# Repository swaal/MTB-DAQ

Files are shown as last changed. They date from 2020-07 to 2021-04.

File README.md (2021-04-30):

# MTB DAQ
A small and portable data acquisition system based on the PyBoard V1.1 designed to collect acceleration data while riding a mountain bike.

## About
The Mountain Bike Data Acquisition System (MTB DAQ) is a system designed to collect acceleration data while riding a mountain bike.
The system was designed as part of a Cal Poly Masters Thesis in Mechanical Engineering focused on a quantitative method for tuning mountain bike suspension. The MTB DAQ
was designed after the PyBoard V1.1 and is utilizes the same firmware. The acceleration data is stored in binary format on a Micro SD card. 

## Contents
The files included in this project provide almost everything needed to build a MTB DAQ. The folders are arranged as follows:
### BoardFiles
This folder contains all of the Autodesk Eagle schematic and board files. There are three types of boards: the Main Board, the UI Board, and the ADXL375 Board. 
The Main Board and UI Board work together to define the heart of the system, providing the computing power and user interface. The ADXL375 Board provides the necessary power filtering and connections for the ADXL375 accelerometer. The accelerometers are connected to the main board via two ethernet cables, chosen for their wide availability, low cost, and locking connection.
### MATLAB_Code
This folder contains two MATLAB files that can be used to interpret and plot the acceleration data from the binary files that are saved from the MTB DAQ.
### MicropythonCode
This folder contains the micropython files that run the MTB DAQ. Note that some of the files have been saved as *.mpy* files. This is a bytecote version of the original file. This was done in order to make the files small enough to fit in the flash memory of the microcontroller. The original files are contained within the sub folder "files_converted_to_mpy". Any modifications made to the original *.py* files can be converted into *.mpy* files using the python cross compiler *mpy-cross*. To get the system running, simply load on all the files in the MicropythonCode folder (excluding the contents in the files_converted_to_mpy subfolder) and reboot the board.
### PyBoardFirmware
A copy of the compatible PyBoard V1.1 firmware.

## Technical Specifications
- **Accelerometers:** Analog Devices ADXL375BCCZ Accelerometer
- **Number of Accelerometers Supported:** 2
- **Measurement Range:** +/- 200g
- **Output Data Rate:** 1600Hz (can be configured to go up to 3200Hz)
- **Battery Life:** > 8 hours

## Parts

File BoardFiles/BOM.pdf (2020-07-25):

ASSEMBLY | SUB ASSEMBLY | PART | DESCRIPTION | MFG. | MFG. PART NO. | SUPPLIER | SUPPLIER PART NO. | QTY/UNIT
MAIN UNIT | - | EXTRUSION | BOX ALUM NATURAL 4.72"LX3.07"W | HAMMOND MANUFACTURING | 1455J1201 | DIGIKEY | HM890-ND | 1
MAIN UNIT | - | JUMPER | JUMPER W/TEST PNT 1X2PINS 2.54MM | WÜRTH ELEKTRONIK | 60900213421 | DIGIKEY | 732-2678-ND | 1
MAIN UNIT | - | M5X0.8 35MM LONG HEX CAP
| | SCREW | SUPER-CORROSION-RESISTANT 316
| | | STAINLESS STEEL SOCKET HEAD SCREW;
| | | M5 X 0.8 MM THREAD, 35 MM LONG | | | MCMASTER | 92290A256 | 2
MAIN UNIT | - | POWER SWITCH | SWITCH ROCKER SPST 10A 125V | E-SWITCH | R6ABLKBLKFF | DIGIKEY | EG1526-ND | 1
MAIN UNIT | - | QUICK CONNECT CABLE CRIMP | CONN QC RCPT 14-18AWG 0.187 | TE CONNECTIVITY | 63316-2 | DIGIKEY | A100922CT-ND | 4
MAIN UNIT | - | RECEPTCLE SLEEVE | CONN RCPT SLEEVE 0.187 1POS CLR | TE CONNECTIVITY | 3-170823-8 | DIGIKEY | A124425-ND | 4
MAIN UNIT | - | RIBBON CABLE | CABLE ASSEM .05" 10POS F-F 2" | SAMTEC INC. | FFSD-05-D-02.00-01-N | DIGIKEY | SAM8217-ND | 1
MAIN UNIT | - | THREAD LOCKER | ADJUSTABLE THREAD LOCKER; 0.34 OZ.
| | | CAN | LOCTITE | 222 | MCMASTER | 1810A27 | 0.01
MAIN UNIT | - | SIDE PANEL 1 | | LASER CUT | | | | 1
MAIN UNIT | - | SIDE PANEL 2 | | LASER CUT | | | | 1
MAIN UNIT | MAIN BOARD | MAIN BOARD PCB | MAIN BOARD PRINTED CIRCUIT BOARD | OSHPARK | | OSHPARK | | 1
MAIN UNIT | MAIN BOARD | (-). (+) | DIGIKEY PART NO. WM6456-ND | MOLEX | 197084011 | DIGIKEY | WM6456-ND | 2
MAIN UNIT | MAIN BOARD | ADXL375_1, ADXL375_2 | DIGIKEY PART NO. RJCSE538001CT- | AMPHENOL ICC (COMMERCIAL
| | | | PRODUCTS) | RJCSE538001 | DIGIKEY | RJCSE538001CT-ND | 2
MAIN UNIT | MAIN BOARD | BAT_1, BAT_2 | PH SERIES 2 POSITION 2 MM PITCH | JST SALES AMERICA INC. | S2B-PH-SM4-TB(LF)(SN) | DIGIKEY | 455-1749-1-ND | 2
MAIN UNIT | MAIN BOARD | C1, C20, C21, C22, C23, C5 | CAP CER 0.1UF 25V X7R 0805 | KEMET | C0805C104K3RACTU | DIGIKEY | 399-1168-1-ND | 6
MAIN UNIT | MAIN BOARD | C15, C16 | CAP CER 1UF 16V X7R 0805 | KEMET | C0805C105K4RACTU | DIGIKEY | 399-1284-1-ND | 2
MAIN UNIT | MAIN BOARD | C17, C18, C19 | CAP CER 4.7UF 6.3V X5R 0805 | KEMET | C0805C475K9PACTU | DIGIKEY | 399-3134-1-ND | 3
MAIN UNIT | MAIN BOARD | C2, C8 | CAP CER 2PF 250V C0G/NP0 0805 | KEMET | CBR08C209BAGAC | DIGIKEY | 399-8701-1-ND | 2
MAIN UNIT | MAIN BOARD | C3, C4 | CAP CER 24PF 250V C0G/NP0 0805 | KEMET | CBR08C240JAGAC | DIGIKEY | 399-8758-1-ND | 2
MAIN UNIT | MAIN BOARD | C6, C7 | CAP CER 2.2UF 10V X7R 0805 | KEMET | C0805C225K8RACAUTO | DIGIKEY | 399-6951-1-ND | 2
MAIN UNIT | MAIN BOARD | C9 | CAP CER 10UF 10V X5R 0805 | KEMET | C0805C106K8PACTU | DIGIKEY | 399-4925-1-ND | 1
MAIN UNIT | MAIN BOARD | D1 | DIODE SCHOTTKY 20V 1A SOD123W | NEXPERIA USA INC. | PMEG2010ER,115 | DIGIKEY | 1727-5192-1-ND | 1
MAIN UNIT | MAIN BOARD | J1 | CONN RCPT USB2.0 MINI B SMD R/A | MOLEX | 675031020 | DIGIKEY | WM5461CT-ND | 1
MAIN UNIT | MAIN BOARD | JP1 | CONN HEADER VERT 3POS 2.54MM | WÜRTH ELEKTRONIK | 61300311121 | DIGIKEY | 732-5316-ND | 1
MAIN UNIT | MAIN BOARD | L1 | 120 OHMS @ 100MHZ 1 FERRITE BE | VISHAY DALE | ILHB0805ER121V | DIGIKEY | 541-2299-1-ND | 1
MAIN UNIT | MAIN BOARD | LED_BLU | LED BLUE CLEAR 0805 SMD | WÜRTH ELEKTRONIK | 150080BS75000 | DIGIKEY | 732-4982-1-ND | 1
MAIN UNIT | MAIN BOARD | LED_GRN | LED GREEN CLEAR 0805 SMD | WÜRTH ELEKTRONIK | 150080VS75000 | DIGIKEY | 732-4986-1-ND | 1
MAIN UNIT | MAIN BOARD | LED_RED | LED RED CLEAR 0805 SMD | WÜRTH ELEKTRONIK | 150080SS75000 | DIGIKEY | 732-4985-1-ND | 1
MAIN UNIT | MAIN BOARD | LED_YEL | LED YELLOW CLEAR 0805 SMD | WÜRTH ELEKTRONIK | 150080YS75000 | DIGIKEY | 732-4987-1-ND | 1
MAIN UNIT | MAIN BOARD | LIPO_CHG | IC CONTROLLR LI-ION 4.2V SOT23-5 | MICROCHIP TECHNOLOGY | MCP73831T-2ACI/OT | DIGIKEY | MCP73831T-
| | | | | | | 2ACI/OTCT-ND | 1
MAIN UNIT | MAIN BOARD | LITHIUM ION BATTERY | BATTERY LITHIUM 3.7V 1.2AH | ADAFRUIT INDUSTRIES LLC | 258 | DIGIKEY | 1528-1838-ND | 1
MAIN UNIT | MAIN BOARD | LITHIUM POLYMER BATTERY | BATT LITH POLY 1S1P 320MAH 3.7V | JAUCH QUARTZ | LP402535JU + PCM +
| | | | | WIRES 50MM | DIGIKEY | 1908-1354-ND | 4
MAIN UNIT | MAIN BOARD | R1, R13, R5, R6, R8 | RES SMD 100K OHM 1% 1/3W 0805 | TE CONNECTIVITY | CRGH0805F100K | DIGIKEY | A126415CT-ND | 5
MAIN UNIT | MAIN BOARD | R11 | RES SMD 2K OHM 0.1% 1/4W 0805 | TE CONNECTIVITY | RP73PF2A2K0BTDF | DIGIKEY | A110572CT-ND | 1
MAIN UNIT | MAIN BOARD | R19, R20, R21, R22, R3 | CRGCQ 0805 4K7 1% | TE CONNECTIVITY | CRGCQ0805F4K7 | DIGIKEY | A129757CT-ND | 5
MAIN UNIT | MAIN BOARD | R2, R10, R15, R16, R17, R18 | RES SMD 560 OHM 1% 1/8W 0805 | TE CONNECTIVITY | CRG0805F560R | DIGIKEY | A126376CT-ND | 6
MAIN UNIT | MAIN BOARD | R7, R9 | RES SMD 22 OHM 1% 1/8W 0805 | TE CONNECTIVITY | CRG0805F22R | DIGIKEY | A126352CT-ND | 2
MAIN UNIT | MAIN BOARD | RESET | SWITCH TACTILE SPST-NO 0.05A 12V | E-SWITCH | TL3301FF160QG | DIGIKEY | EG4375CT-ND | 1
MAIN UNIT | MAIN BOARD | SD_SLOT | CONN MICRO SD CARD PUSH-PUSH R/A | MOLEX | 5027740891 | DIGIKEY | WM24066CT-ND | 1
MAIN UNIT | MAIN BOARD | STM32F405RGT6 | IC MCU 32BIT 1MB FLASH 64LQFP | STMICROELECTRONICS | STM32F405RGT6 | DIGIKEY | 497-11767-ND | 1
MAIN UNIT | MAIN BOARD | U1 | IC REG LINEAR 3.3V 1A SOT223 | DIODES INCORPORATED | AZ1117EH-3.3TRG1 | DIGIKEY | AZ1117EH-
| | | | | | | 3.3TRG1DICT-ND | 1
MAIN UNIT | MAIN BOARD | X1 | CONN HEADER SMD 10POS 1.27MM | SAMTEC INC. | SHF-105-01-L-D-SM | DIGIKEY | SAM10710-ND | 1
MAIN UNIT | MAIN BOARD | XTAL | CRYSTAL 12.0000MHZ 18PF SMD | ECS INC. | ECS-120-18-5PX-TR | DIGIKEY | XC1289CT-ND | 1
MAIN UNIT | MAIN BOARD | Y1 | CRYSTAL 32.7680KHZ 6PF SMD | ABRACON LLC | ABS25-32.768KHZ-6-1-T | DIGIKEY | 535-10241-1-ND | 1
MAIN UNIT | UI BOARD | UI BOARD PCB | UI BOARD PRINTED CIRCUIT BOARD | OSHPARK | | OSHPARK | | 1
MAIN UNIT | UI BOARD | LED HOLDER | LED HOLDER | 3D PRINTED | | | | 1
MAIN UNIT | UI BOARD | 7 SEGMENT DISPLAY | QUAD ALPHANUMERIC DISPLAY - RED 0.54"
| | | DIGITS W/ I2C BACKPACK | ADAFRUIT INDUSTRIES LLC | 1911 | ADAFRUIT | 1911 | 1
MAIN UNIT | UI BOARD | CHG | PNL MNT W/ WIRE 590NM 25MCD YLW | BIVAR INC. | MPR5YD | DIGIKEY | 492-1576-ND | 1
MAIN UNIT | UI BOARD | PWR | PNL MNT W/ WIRE 568NM 25MCD GRN | BIVAR INC. | MPR5GD | DIGIKEY | 492-1571-ND | 1
MAIN UNIT | UI BOARD | R1, R3 | RES SMD 44.2 OHM 0.1% 1/4W 0805 | TE CONNECTIVITY | 8-1625868-9 | DIGIKEY | A110413CT-ND | 2
MAIN UNIT | UI BOARD | R2 | RES SMD 80.6 OHM 0.1% 1/4W 0805 | TE CONNECTIVITY | 1-2176091-5 | DIGIKEY | A110438CT-ND | 1
MAIN UNIT | UI BOARD | R4 | CRGCQ 0805 4K7 1% | TE CONNECTIVITY | CRGCQ0805F4K7 | DIGIKEY | A129757CT-ND | 1
MAIN UNIT | UI BOARD | REC | PNL MNT W/ WIRE 625NM 25MCD RED | BIVAR INC. | MPR5HD | DIGIKEY | 492-1573-ND | 1
| | | SPLINED PRESS-FIT THREADED STANDOFFS WITH OPEN END; MINIATURE, 2.4MM OD, 2MM LONG
MAIN UNIT | UI BOARD | U$4 | SWITCH PUSHBUTTON SPST-NO 2A 48V | E-SWITCH | PV0H240SS | DIGIKEY | EG5385-ND | 1
MAIN UNIT | UI BOARD | STANDOFFS | | | | MCMASTER | 92985A815 | 4
MAIN UNIT | UI BOARD | X1 | CONN HEADER SMD 10POS 1.27MM | SAMTEC INC. | SHF-105-01-L-D-SM | DIGIKEY | SAM10710-ND | 1

ASSEMBLY | SUB ASSEMBLY | PART | DESCRIPTION | MFG. | MFG. PART NO. | SUPPLIER | SUPPLIER PART NO. | QTY/UNIT
MAIN UNIT | UI BOARD | | 316 STAINLESS STEEL WASHER; FOR
| | | NUMBER 3 SCREW SIZE, 0.109" ID, 0.25" OD | | | MCMASTER | 90107A004 | 4
MAIN UNIT | UI BOARD | | ALUMINUM UNTHREADED SPACER; 1/4" OD,
| | | 3/16" LONG, FOR NUMBER 2 SCREW SIZE | | | MCMASTER | 92510A401 | 4
MAIN UNIT | UI BOARD | | 18-8 STAINLESS STEEL WASHER FOR M1 SCREW SIZE, 1.1 MM ID, 3.2 MM OD | | MCMASTER | 93475A154 | 8
| | | 18-8 STAINLESS STEEL NARROW CHEESE HEAD SLOTTED SCREWS; M1 X 0.25MM THREAD, 10MM LONG
FRONT ACCELEROMETER UNIT | ADXL375 BOARD | ADXL375 BOARD PCB | ADXL375 BOARD PRINTED CIRCUIT BOARD | OSHPARK | OSHPARK | | 1
MAIN UNIT | UI BOARD
MCMASTER | 91800A062 | 4
FRONT ACCELEROMETER UNIT | ADXL375 BOARD | U1 | IC GATE OR 1CH 2-INP SC70-5 | TEXAS INSTRUMENTS | SN74LVC1G32DCKR | DIGIKEY | 296-9848-1-ND | 1
FRONT ACCELEROMETER UNIT | ADXL375 BOARD | RJ45 | DIGIKEY PART NO. RJCSE538001CT- | AMPHENOL ICC (COMMERCIAL
| | | | PRODUCTS) | RJCSE538001 | DIGIKEY | RJCSE538001CT-ND | 1
FRONT ACCELEROMETER UNIT | ADXL375 BOARD | L1 | FERRITE BEAD 30 OHM 0805 1LN | BOURNS INC. | MH2029-300Y | DIGIKEY | MH2029-300YCT-ND | 1
FRONT ACCELEROMETER UNIT | ADXL375 BOARD | C3, C1 | CAP CER 0.1UF 25V X7R 0805 | KEMET | C0805C104K3RACTU | DIGIKEY | 399-1168-1-ND | 2
FRONT ACCELEROMETER UNIT | ADXL375 BOARD | C2 | CAP CER 10UF 10V X5R 0805 | KEMET | C0805C106K8PACTU | DIGIKEY | 399-4925-1-ND | 1
FRONT ACCELEROMETER UNIT | ADXL375 BOARD | ADXL375 | ACCELEROMETER 200G I2C/SPI 14LGA | ANALOG DEVICES INC. | ADXL375BCCZ | DIGIKEY | ADXL375BCCZ-ND | 1
FRONT ACCELEROMETER UNIT | - | FRONT MOUNT BLOCK | FRONT MOUNT BLOCK | 3D PRINTED | | | | 1
FRONT ACCELEROMETER UNIT | - | FRONT COVER | FRONT COVER RUBBER-CUSHIONED U-BOLT; 304 | 3D PRINTED | | | 1
| | | STAINLESS STEEL, 3/8"-16 THREAD SIZE, 1-7/8" ID
FRONT ACCELEROMETER UNIT | - | M3X0.5 BRASS INSERTS | BRASS HEAT-SET INSERTS FOR PLASTIC; M3 X 0.50 MM THREAD SIZE, 5.700 MM INSTALLED LENGTH | | MCMASTER | 94459A140 | 4
| | | STAINLESS STEEL PAN HEAD SCREWS; WITH EXTERNAL-TOOTH WASHER, M3 X 0.5 MM THREAD, 6 MM LONG
FRONT ACCELEROMETER UNIT | - | 1/4" WASHER | 316 STAINLESS STEEL WASHER; FOR 1/4" SCREW SIZE, 0.281" ID, 0.625" OD | | MCMASTER | 90107A029 | 4
FRONT ACCELEROMETER UNIT | - | LARGE U-BOLT
MCMASTER | 30555T43 | 2
FRONT ACCELEROMETER UNIT | - | SCREW; PHILLIPS; M3X0.5X6
MCMASTER | 90317A523 | 4
REAR ACCELEROMETER UNIT | ADXL375 BOARD | ADXL375 BOARD PCB | ADXL375 BOARD PRINTED CIRCUIT BOARD | OSHPARK | | OSHPARK | | 1
REAR ACCELEROMETER UNIT | ADXL375 BOARD | U1 | IC GATE OR 1CH 2-INP SC70-5 | TEXAS INSTRUMENTS | SN74LVC1G32DCKR | DIGIKEY | 296-9848-1-ND | 1
REAR ACCELEROMETER UNIT | ADXL375 BOARD | RJ45 | DIGIKEY PART NO. RJCSE538001CT- | AMPHENOL ICC (COMMERCIAL
| | | | PRODUCTS) | RJCSE538001 | DIGIKEY | RJCSE538001CT-ND | 1
REAR ACCELEROMETER UNIT | ADXL375 BOARD | L1 | FERRITE BEAD 30 OHM 0805 1LN | BOURNS INC. | MH2029-300Y | DIGIKEY | MH2029-300YCT-ND | 1
REAR ACCELEROMETER UNIT | ADXL375 BOARD | C3, C1 | CAP CER 0.1UF 25V X7R 0805 | KEMET | C0805C104K3RACTU | DIGIKEY | 399-1168-1-ND | 2
REAR ACCELEROMETER UNIT | ADXL375 BOARD | C2 | CAP CER 10UF 10V X5R 0805 | KEMET | C0805C106K8PACTU | DIGIKEY | 399-4925-1-ND | 1
REAR ACCELEROMETER UNIT | ADXL375 BOARD | ADXL375 | ACCELEROMETER 200G I2C/SPI 14LGA | ANALOG DEVICES INC. | ADXL375BCCZ | DIGIKEY | ADXL375BCCZ-ND | 1
REAR ACCELEROMETER UNIT | - | REAR MOUNT BLOCK | REAR MOUNT BLOCK | 3D PRINTED | | | | 1
REAR ACCELEROMETER UNIT | - | REAR COVER | REAR COVER | 3D PRINTED | | | | 1
REAR ACCELEROMETER UNIT | - | REAR TRIANGLE ADAPTER | REAR TRIANGLE ADAPTER RUBBER-CUSHIONED U-BOLT; 304 | 3D PRINTED | | | 1
| | | STAINLESS STEEL, 1/4"-20 THREAD SIZE, 1-1/4" ID
REAR ACCELEROMETER UNIT | - | M3X0.5 BRASS INSERTS | BRASS HEAT-SET INSERTS FOR PLASTIC; M3 X 0.50 MM THREAD SIZE, 5.700 MM INSTALLED LENGTH | | MCMASTER | 94459A140 | 4
| | | STAINLESS STEEL PAN HEAD SCREWS; WITH EXTERNAL-TOOTH WASHER, M3 X 0.5 MM THREAD, 6 MM LONG
REAR ACCELEROMETER UNIT | - | 1/4" WASHER | 316 STAINLESS STEEL WASHER; FOR 1/4" SCREW SIZE, 0.281" ID, 0.625" OD | | MCMASTER | 90107A029 | 4
REAR ACCELEROMETER UNIT | - | SMALL U-BOLT
MCMASTER | 30555T42 | 2
REAR ACCELEROMETER UNIT | - | SCREW; PHILLIPS; M3X0.5X6
MCMASTER | 90317A523 | 4

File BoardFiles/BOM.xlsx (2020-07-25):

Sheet: MASTER
 | UNIT TOTAL | 265.8501333 |  | ORDER TOTAL | 0
ASSEMBLY | SUB ASSEMBLY | PART | VALUE | DEVICE | PACKAGE | DESCRIPTION | MFG. | MFG. PART NO. | SUPPLIER | SUPPLIER PART NO. | LINK | QTY/UNIT | PRICE | EA -> EA | QTY. | TOTAL | EXTRA TO ORDER | TOTAL ORDERED | ORDER PRICE
MAIN UNIT | - | EXTRUSION | - |  |  | BOX ALUM NATURAL 4.72"LX3.07"W | Hammond Manufacturing | 1455J1201 | DIGIKEY | HM890-ND | https://www.digikey.com/product-detail/en/hammond-manufacturing/1455J1201/HM890-ND/1090702 | 1 | 18.21 | 1 | 1 | 18.21
MAIN UNIT | - | JUMPER | - |  |  | JUMPER W/TEST PNT 1X2PINS 2.54MM | Würth Elektronik | 60900213421 | DIGIKEY | 732-2678-ND | https://www.digikey.com/product-detail/en/würth-elektronik/60900213421/732-2678-ND/2508447 | 1 | 0.3 | 1 | 1 | 0.3
MAIN UNIT | - | M5X0.8 35MM LONG HEX CAP SCREW |  |  |  | Super-Corrosion-Resistant 316 Stainless Steel Socket Head Screw; M5 x 0.8 mm Thread, 35 mm Long |  |  | MCMASTER | 92290A256 | https://www.mcmaster.com/92290a256 | 2 | 6.55 | 10 | 1 | 6.55
MAIN UNIT | - | POWER SWITCH | - |  |  | SWITCH ROCKER SPST 10A 125V | E-Switch | R6ABLKBLKFF | DIGIKEY | EG1526-ND | https://www.digikey.com/product-detail/en/e-switch/R6ABLKBLKFF/EG1526-ND/301973 | 1 | 1.61 | 1 | 1 | 1.61
MAIN UNIT | - | QUICK CONNECT CABLE CRIMP | - |  |  | CONN QC RCPT 14-18AWG 0.187 | TE Connectivity AMP Connectors | 63316-2 | DIGIKEY | A100922CT-ND | https://www.digikey.com/product-detail/en/te-connectivity-amp-connectors/63316-2/A100922CT-ND/2259591 | 4 | 0.22 | 1 | 4 | 0.88
MAIN UNIT | - | RECEPTCLE SLEEVE | - |  |  | CONN RCPT SLEEVE 0.187 1POS CLR | TE Connectivity AMP Connectors | 3-170823-8 | DIGIKEY | A124425-ND | https://www.digikey.com/product-detail/en/te-connectivity-amp-connectors/3-170823-8/A124425-ND/2284645 | 4 | 0.18 | 1 | 4 | 0.72
MAIN UNIT | - | RIBBON CABLE | - |  |  | CABLE ASSEM .05" 10POS F-F 2" | Samtec Inc. | FFSD-05-D-02.00-01-N | DIGIKEY | SAM8217-ND | https://www.digikey.com/product-detail/en/samtec-inc/FFSD-05-D-02-00-01-N/SAM8217-ND/1106576 | 1 | 11.18 | 1 | 1 | 11.18
MAIN UNIT | - | THREAD LOCKER |  |  |  | ADJUSTABLE THREAD LOCKER; 0.34 OZ. CAN | LOCTITE | 222 | MCMASTER | 1810A27 | https://www.mcmaster.com/1810a27 | 0.01 | 15.35 | 1 | 1 | 15.35
MAIN UNIT | - | SIDE PANEL 1 |  |  |  |  | LASER CUT
MAIN UNIT | - | SIDE PANEL 2 |  |  |  |  | LASER CUT
MAIN UNIT | MAIN BOARD | MAIN BOARD PCB |  |  |  | MAIN BOARD PRINTED CIRCUIT BOARD | OSHPARK |  | OSHPARK |  |  | 1 | 70.9 | 3 | 1 | 23.63333333
MAIN UNIT | MAIN BOARD | (-). (+) | QUICK_CONNECT_0.187" | QUICK_CONNECT_0.187" | QUICK_CONNECT_0.187" | DIGIKEY PART NO. WM6456-ND | MOLEX | 197084011 | DIGIKEY | WM6456-ND | https://www.digikey.com/product-detail/en/molex/0197084011/WM6456-ND/459342 | 2 | 0.22 | 1 | 0.44 | 0.0968
MAIN UNIT | MAIN BOARD | ADXL375_1, ADXL375_2 | RJ45_SURFACE_MOUNT | RJ45_SURFACE_MOUNT | RJ45_SURFACE_MOUNT | Digikey Part No. RJCSE538001CT- | Amphenol ICC (Commercial Products) | RJCSE538001 | DIGIKEY | RJCSE538001CT-ND | https://www.digikey.com/products/en?keywords=RJCSE538001CT | 2 | 1.6 | 1 | 2 | 3.2
MAIN UNIT | MAIN BOARD | BAT_1, BAT_2 | S2B-PH-SM4-TB(LF)(SN) | S2B-PH-SM4-TB(LF)(SN) | JST_S2B-PH-SM4-TB(LF)(SN) | PH Series 2 Position 2 mm Pitch | JST Sales America Inc. | S2B-PH-SM4-TB(LF)(SN) | DIGIKEY | 455-1749-1-ND | https://www.digikey.com/product-detail/en/jst-sales-america-inc/S2B-PH-SM4-TB(LF)(SN)/455-1749-1-ND/926846 | 2 | 0.58 | 1 | 2 | 1.16
MAIN UNIT | MAIN BOARD | C1, C20, C21, C22, C23, C5 | 0.1uF | C-USC0805 | C0805 | CAP CER 0.1UF 25V X7R 0805 | KEMET | C0805C104K3RACTU | DIGIKEY | 399-1168-1-ND | https://www.digikey.com/product-detail/en/kemet/C0805C104K3RACTU/399-1168-1-ND/411443 | 6 | 0.15 | 1 | 6 | 0.9
MAIN UNIT | MAIN BOARD | C15, C16 | 1uF | C-USC0805 | C0805 | CAP CER 1UF 16V X7R 0805 | KEMET | C0805C105K4RACTU | DIGIKEY | 399-1284-1-ND | https://www.digikey.com/product-detail/en/kemet/C0805C105K4RACTU/399-1284-1-ND/416060 | 2 | 0.15 |  | 2 | 0.3
MAIN UNIT | MAIN BOARD | C17, C18, C19 | 4.7uF | C-USC0805 | C0805 | CAP CER 4.7UF 6.3V X5R 0805 | KEMET | C0805C475K9PACTU | DIGIKEY | 399-3134-1-ND | https://www.digikey.com/product-detail/en/kemet/C0805C475K9PACTU/399-3134-1-ND/551639 | 3 | 0.21 |  | 3 | 0.63
MAIN UNIT | MAIN BOARD | C2, C8 | 2pF | C-USC0805 | C0805 | CAP CER 2PF 250V C0G/NP0 0805 | KEMET | CBR08C209BAGAC | DIGIKEY | 399-8701-1-ND | https://www.digikey.com/product-detail/en/kemet/CBR08C209BAGAC/399-8701-1-ND/3480301 | 2 | 1.49 |  | 2 | 2.98
MAIN UNIT | MAIN BOARD | C3, C4 | 24pF | C-USC0805 | C0805 | CAP CER 24PF 250V C0G/NP0 0805 | KEMET | CBR08C240JAGAC | DIGIKEY | 399-8758-1-ND | https://www.digikey.com/product-detail/en/kemet/CBR08C240JAGAC/399-8758-1-ND/3481277 | 2 | 1.72 |  | 2 | 3.44
MAIN UNIT | MAIN BOARD | C6, C7 | 2.2uF | C-USC0805 | C0805 | CAP CER 2.2UF 10V X7R 0805 | KEMET | C0805C225K8RACAUTO | DIGIKEY | 399-6951-1-ND | https://www.digikey.com/product-detail/en/kemet/C0805C225K8RACAUTO/399-6951-1-ND/3314459 | 2 | 0.25 |  | 2 | 0.5
MAIN UNIT | MAIN BOARD | C9 | 10uF | C-USC0805 | C0805 | CAP CER 10UF 10V X5R 0805 | KEMET | C0805C106K8PACTU | DIGIKEY | 399-4925-1-ND | https://www.digikey.com/product-detail/en/kemet/C0805C106K8PACTU/399-4925-1-ND/1090920 | 1 | 0.16 |  | 1 | 0.16
MAIN UNIT | MAIN BOARD | D1 | DIODE_SCHOTTKY | DIODE_SCHOTTKY | DIODE_SOD123W_1P9X2P8 | DIODE SCHOTTKY 20V 1A SOD123W | Nexperia USA Inc. | PMEG2010ER,115 | DIGIKEY | 1727-5192-1-ND | https://www.digikey.com/product-detail/en/nexperia-usa-inc/PMEG2010ER-115/1727-5192-1-ND/2531791 | 1 | 0.35 | 1 | 1 | 0.35
MAIN UNIT | MAIN BOARD | J1 | USB_MINI-B_SMT | USB_MINI-B_SMT | USB-MINIB | CONN RCPT USB2.0 MINI B SMD R/A | Molex | 675031020 | DIGIKEY | WM5461CT-ND | https://www.digikey.com/product-detail/en/molex/0675031020/WM5461CT-ND/1624427 | 1 | 1.08 |  | 1 | 1.08
MAIN UNIT | MAIN BOARD | JP1 |  | PINHD-1X3 | 1X03 | CONN HEADER VERT 3POS 2.54MM | Würth Elektronik | 61300311121 | DIGIKEY | 732-5316-ND | https://www.digikey.com/product-detail/en/würth-elektronik/61300311121/732-5316-ND/4846825 | 1 | 0.13 |  | 1 | 0.13
MAIN UNIT | MAIN BOARD | L1 | 1K | BEAD_120OHMS_100MHZ | IND_VISHAY_ILHB0805 | 120 Ohms @ 100MHz 1 Ferrite Be | Vishay Dale | ILHB0805ER121V | DIGIKEY | 541-2299-1-ND | https://www.digikey.com/product-detail/en/vishay-dale/ILHB0805ER121V/541-2299-1-ND/5168396 | 1 | 0.12 | 1 | 1 | 0.12
MAIN UNIT | MAIN BOARD | LED_BLU | LED_0805LED_0805 | LED_0805LED_0805 | 805 | LED BLUE CLEAR 0805 SMD | Würth Elektronik | 150080BS75000 | DIGIKEY | 732-4982-1-ND | https://www.digikey.com/product-detail/en/würth-elektronik/150080BS75000/732-4982-1-ND/4489910 | 1 | 0.18 |  | 1 | 0.18
MAIN UNIT | MAIN BOARD | LED_GRN | LED_0805LED_0805 | LED_0805LED_0805 | 805 | LED GREEN CLEAR 0805 SMD | Würth Elektronik | 150080VS75000 | DIGIKEY | 732-4986-1-ND | https://www.digikey.com/product-detail/en/würth-elektronik/150080VS75000/732-4986-1-ND/4489922 | 1 | 0.18 |  | 1 | 0.18
MAIN UNIT | MAIN BOARD | LED_RED | LED_0805LED_0805 | LED_0805LED_0805 | 805 | LED RED CLEAR 0805 SMD | Würth Elektronik | 150080SS75000 | DIGIKEY | 732-4985-1-ND | https://www.digikey.com/product-detail/en/würth-elektronik/150080SS75000/732-4985-1-ND/4489919 | 1 | 0.18 |  | 1 | 0.18
MAIN UNIT | MAIN BOARD | LED_YEL | LED_0805LED_0805 | LED_0805LED_0805 | 805 | LED YELLOW CLEAR 0805 SMD | Würth Elektronik | 150080YS75000 | DIGIKEY | 732-4987-1-ND | https://www.digikey.com/product-detail/en/würth-elektronik/150080YS75000/732-4987-1-ND/4489925 | 1 | 0.18 |  | 1 | 0.18
MAIN UNIT | MAIN BOARD | LIPO_CHG | LIPO_CHARGER_MCP73831/2 | LIPO_CHARGER_MCP73831/2 | SOT23-5 | IC CONTROLLR LI-ION 4.2V SOT23-5 | Microchip Technology | MCP73831T-2ACI/OT | DIGIKEY | MCP73831T-2ACI/OTCT-ND | https://www.digikey.com/product-detail/en/microchip-technology/MCP73831T-2ACI-OT/MCP73831T-2ACI-OTCT-ND/1979802 | 1 | 0.56 | 1 | 1 | 0.56
MAIN UNIT | MAIN BOARD | LITHIUM ION BATTERY |  |  |  | BATTERY LITHIUM 3.7V 1.2AH | Adafruit Industries LLC | 258 | DIGIKEY | 1528-1838-ND | https://www.digikey.com/product-detail/en/adafruit-industries-llc/258/1528-1838-ND/5054544 | 1 | 9.95 | 1 | 1 | 9.95
MAIN UNIT | MAIN BOARD | LITHIUM POLYMER BATTERY |  |  |  | BATT LITH POLY 1S1P 320MAH 3.7V | Jauch Quartz | LP402535JU + PCM + WIRES 50MM | DIGIKEY | 1908-1354-ND | https://www.digikey.com/product-detail/en/jauch-quartz/LP402535JU---PCM---WIRES-50MM/1908-1354-ND/9560977 | 4 | 9.54 | 1 | 4 | 38.16
MAIN UNIT | MAIN BOARD | R1, R13, R5, R6, R8 | 100K | R-US_R0805 | R0805 | RES SMD 100K OHM 1% 1/3W 0805 | TE Connectivity Passive Product | CRGH0805F100K | DIGIKEY | A126415CT-ND | https://www.digikey.com/product-detail/en/te-connectivity-passive-product/CRGH0805F100K/A126415CT-ND/7603470 | 5 | 0.1 | 1 | 5 | 0.5
MAIN UNIT | MAIN BOARD | R11 | 10K | R-US_R0805 | R0805 | RES SMD 10K OHM 0.1% 1/4W 0805 | TE Connectivity Passive Product | 2176093-5 | DIGIKEY | A110639CT-ND | https://www.digikey.com/products/en/resistors/chip-resistor-surface-mount/52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 | 1 | 0.5 |  | 1 | 0.5
MAIN UNIT | MAIN BOARD | R19, R20, R21, R22, R3 | 4.7K | R-US_R0805 | R0805 | CRGCQ 0805 4K7 1% | TE Connectivity Passive Product | CRGCQ0805F4K7 | DIGIKEY | A129757CT-ND | https://www.digikey.com/product-detail/en/te-connectivity-passive-product/CRGCQ0805F4K7/A129757CT-ND/8577589 | 5 | 0.1 |  | 5 | 0.5
MAIN UNIT | MAIN BOARD | R2, R10, R15, R16, R17, R18 | 560 | R-US_R0805 | R0805 | RES SMD 560 OHM 1% 1/8W 0805 | TE Connectivity Passive Product | CRG0805F560R | DIGIKEY | A126376CT-ND | https://www.digikey.com/product-detail/en/te-connectivity-passive-product/CRG0805F560R/A126376CT-ND/7603431 | 6 | 0.1 | 1 | 6 | 0.6
MAIN UNIT | MAIN BOARD | R7, R9 | 22 | R-US_R0805 | R0805 | RES SMD 22 OHM 1% 1/8W 0805 | TE Connectivity Passive Product | CRG0805F22R | DIGIKEY | A126352CT-ND | https://www.digikey.com/product-detail/en/te-connectivity-passive-product/CRG0805F22R/A126352CT-ND/7603407 | 2 | 0.1 | 1 | 2 | 0.2
MAIN UNIT | MAIN BOARD | RESET | SWITCH | SWITCH | SWITCH_FSM6JSMATR | SWITCH TACTILE SPST-NO 0.05A 12V | E-Switch | TL3301FF160QG | DIGIKEY | EG4375CT-ND | https://www.digikey.com/product-detail/en/e-switch/TL3301FF160QG/EG4375CT-ND/1144805 | 1 | 0.41 | 1 | 1 | 0.41
MAIN UNIT | MAIN BOARD | SD_SLOT | MICRO_SD_SLOT | MICRO_SD_SLOT |  | CONN MICRO SD CARD PUSH-PUSH R/A | Molex | 5027740891 | DIGIKEY | WM24066CT-ND | https://www.digikey.com/product-detail/en/molex/5027740891/WM24066CT-ND/1952536 | 1 | 2.45 | 1 | 1 | 2.45
MAIN UNIT | MAIN BOARD | STM32F405RGT6 | STM32F405RGT6 | STM32F405RG | TQFP64 | IC MCU 32BIT 1MB FLASH 64LQFP | STMicroelectronics | STM32F405RGT6 | DIGIKEY | 497-11767-ND | https://www.digikey.com/product-detail/en/stmicroelectronics/STM32F405RGT6/497-11767-ND/2754208 | 1 | 11.61 | 1 | 1 | 11.61
MAIN UNIT | MAIN BOARD | U1 | AZ1117EH-3.3TRG1 | AZ1117EH-3.3TRG1 | SOT230P700X180-4N | IC REG LINEAR 3.3V 1A SOT223 | Diodes Incorporated | AZ1117EH-3.3TRG1 | DIGIKEY | AZ1117EH-3.3TRG1DICT-ND | https://www.digikey.com/product-detail/en/diodes-incorporated/AZ1117EH-3.3TRG1/AZ1117EH-3.3TRG1DICT-ND/5001336! | 1 | 0.42 | 1 | 1 | 0.42
MAIN UNIT | MAIN BOARD | X1 |  |  |  | CONN HEADER SMD 10POS 1.27MM | Samtec Inc. | SHF-105-01-L-D-SM | DIGIKEY | SAM10710-ND | https://www.digikey.com/product-detail/en/samtec-inc/SHF-105-01-L-D-SM/SAM10710-ND/6561669 | 1 | 2.78 | 1 | 1 | 2.78
MAIN UNIT | MAIN BOARD | XTAL | 12MHZ | XTAL_SFM | HC-49/US | CRYSTAL 12.0000MHZ 18PF SMD | ECS Inc. | ECS-120-18-5PX-TR | DIGIKEY | XC1289CT-ND | https://www.digikey.com/product-detail/en/ecs-inc/ECS-120-18-5PX-TR/XC1289CT-ND/827753 | 1 | 0.5 | 1 | 1 | 0.5
MAIN UNIT | MAIN BOARD | Y1 | 32.768KHZ |  | 4-SOJ, 5.50mm pitch | CRYSTAL 32.7680KHZ 6PF SMD | Abracon LLC | ABS25-32.768KHZ-6-1-T | DIGIKEY | 535-10241-1-ND | https://www.digikey.com/product-detail/en/abracon-llc/ABS25-32.768KHZ-6-1-T/535-10241-1-ND/2218054 | 1 | 0.77 | 1 | 1 | 0.77
MAIN UNIT | UI BOARD | UI BOARD PCB |  |  |  | UI BOARD PRINTED CIRCUIT BOARD | OSHPARK |  | OSHPARK |  |  | 1 | 34.55 | 3 | 1 | 11.51666667
MAIN UNIT | UI BOARD | LED HOLDER |  |  |  | LED HOLDER | 3D PRINTED
MAIN UNIT | UI BOARD | 7 SEGMENT DISPLAY |  |  |  | Quad Alphanumeric Display - Red 0.54" Digits w/ I2C Backpack | ADAFRUIT Industries LLC | 1911 | ADAFRUIT | 1911 | https://www.adafruit.com/product/1911 | 1 | 9.95 | 1 | 1 | 9.95
MAIN UNIT | UI BOARD | CHG | PANEL_MOUNT_LED |  | PANEL_MOUNT_LED | PNL MNT W/ WIRE 590NM 25MCD YLW | Bivar Inc. | MPR5YD | DIGIKEY | 492-1576-ND | https://www.digikey.com/product-detail/en/bivar-inc/MPR5YD/492-1576-ND/3488893 | 1 | 2.49 | 1 | 1 | 2.49
MAIN UNIT | UI BOARD | PWR | PANEL_MOUNT_LED |  | PANEL_MOUNT_LED | PNL MNT W/ WIRE 568NM 25MCD GRN | Bivar Inc. | MPR5GD | DIGIKEY | 492-1571-ND | https://www.digikey.com/product-detail/en/bivar-inc/MPR5GD/492-1571-ND/3488863 | 1 | 2.49 | 1 | 1 | 2.49
MAIN UNIT | UI BOARD | R1, R3 | 44.2 |  | R-US_R0805 | RES SMD 44.2 OHM 0.1% 1/4W 0805 | TE Connectivity Passive Product | 8-1625868-9 | DIGIKEY | A110413CT-ND | https://www.digikey.com/product-detail/en/te-connectivity-passive-product/8-1625868-9/A110413CT-ND/4034768 | 2 | 0.66 | 1 | 2 | 1.32
MAIN UNIT | UI BOARD | R2 | 80.6 |  | R-US_R0805 | RES SMD 80.6 OHM 0.1% 1/4W 0805 | TE Connectivity Passive Product | 1-2176091-5 | DIGIKEY | A110438CT-ND | https://www.digikey.com/product-detail/en/te-connectivity-passive-product/1-2176091-5/A110438CT-ND/4034793 | 1 | 0.62 | 1 | 1 | 0.62
MAIN UNIT | UI BOARD | R4 | 4.7K | R-US_R0805 | R0805 | CRGCQ 0805 4K7 1% | TE Connectivity Passive Product | CRGCQ0805F4K7 | DIGIKEY | A129757CT-ND | https://www.digikey.com/product-detail/en/te-connectivity-passive-product/CRGCQ0805F4K7/A129757CT-ND/8577589 | 1 | 0.1 | 1 | 1 | 0.1
MAIN UNIT | UI BOARD | REC | PANEL_MOUNT_LED |  | PANEL_MOUNT_LED | PNL MNT W/ WIRE 625NM 25MCD RED | Bivar Inc. | MPR5HD | DIGIKEY | 492-1573-ND | https://www.digikey.com/products/en?keywords=492-1573-ND | 1 | 2.49 | 1 | 1 | 2.49
MAIN UNIT | UI BOARD | STANDOFFS |  |  |  | Splined Press-Fit Threaded Standoffs with Open End; Miniature, 2.4mm OD, 2mm Long |  |  | MCMASTER | 92985A815 | https://www.mcmaster.com/92985a815 | 4 | 11.83 | 25 | 1 | 11.83
MAIN UNIT | UI BOARD | U$4 | PANEL_MOUNT_PUSH_ | BUTTON | PANEL_MOUNT_PUSH_BUTTON | SWITCH PUSHBUTTON SPST-NO 2A 48V | E-Switch | PV0H240SS | DIGIKEY | EG5385-ND | https://www.digikey.com/products/en?keywords=EG5385-ND | 1 | 8.52 | 1 | 1 | 8.52
MAIN UNIT | UI BOARD | X1 |  |  |  | CONN HEADER SMD 10POS 1.27MM | Samtec Inc. | SHF-105-01-L-D-SM | DIGIKEY | SAM10710-ND | https://www.digikey.com/product-detail/en/samtec-inc/SHF-105-01-L-D-SM/SAM10710-ND/6561669 | 1 | 2.78 | 1 | 1 | 2.78
MAIN UNIT | UI BOARD |  |  |  |  | 316 Stainless Steel Washer; for Number 3 Screw Size, 0.109" ID, 0.25" OD |  |  | MCMASTER | 90107A004 | https://www.mcmaster.com/90107a004 | 4 | 2.82 | 100 | 1 | 2.82
MAIN UNIT | UI BOARD |  |  |  |  | Aluminum Unthreaded Spacer; 1/4" OD, 3/16" Long, for Number 2 Screw Size |  |  | MCMASTER | 92510A401 | https://www.mcmaster.com/92510a401 | 4 | 0.27 | 1 | 4 | 1.08
MAIN UNIT | UI BOARD |  |  |  |  | 18-8 Stainless Steel Washer for M1 Screw Size, 1.1 mm ID, 3.2 mm OD |  |  | MCMASTER | 93475A154 | https://www.mcmaster.com/93475a154 | 8 | 3.84 | 100 | 1 | 3.84
MAIN UNIT | UI BOARD |  |  |  |  | 18-8 Stainless Steel Narrow Cheese Head Slotted Screws; M1 x 0.25mm Thread, 10mm Long |  |  | MCMASTER | 91800A062 | https://www.mcmaster.com/91800a062 | 4 | 8 | 5 | 1 | 8
FRONT ACCELEROMETER UNIT | ADXL375 BOARD | ADXL375 PCB |  |  |  | ADXL375 PRINTED CIRCUIT BOARD | OSHPARK |  | OSHPARK |  |  | 1 | 6.8 | 3 | 1 | 2.266666667
FRONT ACCELEROMETER UNIT | ADXL375 BOARD | U1 |  |  |  | IC GATE OR 1CH 2-INP SC70-5 | Texas Instruments | SN74LVC1G32DCKR | DIGIKEY | 296-9848-1-ND | https://www.digikey.com/product-detail/en/texas-instruments/SN74LVC1G32DCKR/296-9848-1-ND/380106 | 1 | 0.29 | 1 | 1 | 0.29
FRONT ACCELEROMETER UNIT | ADXL375 BOARD | RJ45 |  |  |  | Digikey Part No. RJCSE538001CT- | Amphenol ICC (Commercial Products) | RJCSE538001 | DIGIKEY | RJCSE538001CT-ND | https://www.digikey.com/products/en?keywords=RJCSE538001CT | 1 | 1.6 | 1 | 1 | 1.6
FRONT ACCELEROMETER UNIT | ADXL375 BOARD |  |  |  |  | FERRITE BEAD 30 OHM 0805 1LN | Bourns Inc. | MH2029-300Y | DIGIKEY | MH2029-300YCT-ND | https://www.digikey.com/product-detail/en/bourns-inc/MH2029-300Y/MH2029-300YCT-ND/3741761 | 1 | 0.1 | 1 | 1 | 0.1
FRONT ACCELEROMETER UNIT | ADXL375 BOARD | C3, C1 | 0.1uF | C-USC0805 | C0805 | CAP CER 0.1UF 25V X7R 0805 | KEMET | C0805C104K3RACTU | DIGIKEY | 399-1168-1-ND | https://www.digikey.com/product-detail/en/kemet/C0805C104K3RACTU/399-1168-1-ND/411443 | 2 | 0.15 | 1 | 2 | 0.3
FRONT ACCELEROMETER UNIT | ADXL375 BOARD | C2 | 10uF | C-USC0805 | C0805 | CAP CER 10UF 10V X5R 0805 | KEMET | C0805C106K8PACTU | DIGIKEY | 399-4925-1-ND | https://www.digikey.com/product-detail/en/kemet/C0805C106K8PACTU/399-4925-1-ND/1090920 | 1 | 0.16 | 1 | 1 | 0.16
FRONT ACCELEROMETER UNIT | ADXL375 BOARD | ADXL375 |  |  |  | ACCELEROMETER 200G I2C/SPI 14LGA | Analog Devices Inc. | ADXL375BCCZ | DIGIKEY | ADXL375BCCZ-ND | https://www.digikey.com/product-detail/en/analog-devices-inc/ADXL375BCCZ/ADXL375BCCZ-ND/4376342 | 1 | 11.23 | 1 | 1 | 11.23
FRONT ACCELEROMETER UNIT | - | FRONT MOUNT BLOCK |  |  |  | FRONT MOUNT BLOCK | 3D PRINTED |  |  |  |  | 1 |  |  | 1
FRONT ACCELEROMETER UNIT | - | FRONT COVER |  |  |  | FRONT COVER | 3D PRINTED |  |  |  |  | 1
FRONT ACCELEROMETER UNIT | - | LARGE U-BOLT |  |  |  | Rubber-Cushioned U-Bolt; 304 Stainless Steel, 3/8"-16 Thread Size, 1-7/8" ID |  |  | MCMASTER | 30555T43 | https://www.mcmaster.com/30555T43-30555T43 | 2 |  |  | 2
FRONT ACCELEROMETER UNIT | - | M3X0.5 BRASS INSERTS |  |  |  | Brass Heat-Set Inserts for Plastic; M3 x 0.50 mm Thread Size, 5.700 mm Installed Length |  |  | MCMASTER | 94459A140 | https://www.mcmaster.com/94459A140-94459A140 | 4 |  |  | 4 | 0
FRONT ACCELEROMETER UNIT | - | SCREW; PHILLIPS; M3X0.5X6 |  |  |  | Stainless Steel Pan Head Screws; with External-Tooth Washer, M3 x 0.5 mm Thread, 6 mm Long |  |  | MCMASTER | 90317A523 | https://www.mcmaster.com/90317A523-90317A523 | 4 |  |  | 4 | 0
FRONT ACCELEROMETER UNIT | - | 1/4" WASHER |  |  |  | 316 Stainless Steel Washer; for 1/4" Screw Size, 0.281" ID, 0.625" OD |  |  | MCMASTER | 90107A029 | https://www.mcmaster.com/90107A029-90107A029 | 4 |  |  | 4 | 0
REAR ACCELEROMETER UNIT | ADXL375 BOARD | ADXL375 PCB |  |  |  | ADXL375 PRINTED CIRCUIT BOARD | OSHPARK |  | OSHPARK |  |  | 1 | 6.8 | 3 | 1 | 2.266666667
REAR ACCELEROMETER UNIT | ADXL375 BOARD | U1 |  |  |  | IC GATE OR 1CH 2-INP SC70-5 | Texas Instruments | SN74LVC1G32DCKR | DIGIKEY | 296-9848-1-ND | https://www.digikey.com/product-detail/en/texas-instruments/SN74LVC1G32DCKR/296-9848-1-ND/380106 | 1 | 0.29 | 1 | 1 | 0.29
REAR ACCELEROMETER UNIT | ADXL375 BOARD | RJ45 |  |  |  | Digikey Part No. RJCSE538001CT- | Amphenol ICC (Commercial Products) | RJCSE538001 | DIGIKEY | RJCSE538001CT-ND | https://www.digikey.com/products/en?keywords=RJCSE538001CT | 1 | 1.6 | 1 | 1 | 1.6
REAR ACCELEROMETER UNIT | ADXL375 BOARD | L1 |  |  |  | FERRITE BEAD 30 OHM 0805 1LN | Bourns Inc. | MH2029-300Y | DIGIKEY | MH2029-300YCT-ND | https://www.digikey.com/product-detail/en/bourns-inc/MH2029-300Y/MH2029-300YCT-ND/3741761 | 1 | 0.1 | 1 | 1 | 0.1
REAR ACCELEROMETER UNIT | ADXL375 BOARD | C3, C1 | 0.1uF | C-USC0805 | C0805 | CAP CER 0.1UF 25V X7R 0805 | KEMET | C0805C104K3RACTU | DIGIKEY | 399-1168-1-ND | https://www.digikey.com/product-detail/en/kemet/C0805C104K3RACTU/399-1168-1-ND/411443 | 2 | 0.15 | 1 | 2 | 0.3
REAR ACCELEROMETER UNIT | ADXL375 BOARD | C2 | 10uF | C-USC0805 | C0805 | CAP CER 10UF 10V X5R 0805 | KEMET | C0805C106K8PACTU | DIGIKEY | 399-4925-1-ND | https://www.digikey.com/product-detail/en/kemet/C0805C106K8PACTU/399-4925-1-ND/1090920 | 1 | 0.16 | 1 | 1 | 0.16
REAR ACCELEROMETER UNIT | ADXL375 BOARD | ADXL375 |  |  |  | ACCELEROMETER 200G I2C/SPI 14LGA | Analog Devices Inc. | ADXL375BCCZ | DIGIKEY | ADXL375BCCZ-ND | https://www.digikey.com/product-detail/en/analog-devices-inc/ADXL375BCCZ/ADXL375BCCZ-ND/4376342 | 1 | 11.23 | 1 | 1 | 11.23
REAR ACCELEROMETER UNIT | - | REAR MOUNT BLOCK |  |  |  | REAR MOUNT BLOCK | 3D PRINTED |  |  |  |  | 1 |  |  | 1
REAR ACCELEROMETER UNIT | - | REAR COVER |  |  |  | REAR COVER | 3D PRINTED |  |  |  |  | 1
REAR ACCELEROMETER UNIT | - | REAR TRIANGLE ADAPTER |  |  |  | REAR TRIANGLE ADAPTER | 3D PRINTED |  |  |  |  | 1 |  |  | 1
REAR ACCELEROMETER UNIT | - | SMALL U-BOLT |  |  |  | Rubber-Cushioned U-Bolt; 304 Stainless Steel, 1/4"-20 Thread Size, 1-1/4" ID |  |  | MCMASTER | 30555T42 | https://www.mcmaster.com/30555T42-30555T42 | 2 |  |  | 2
REAR ACCELEROMETER UNIT | - | M3X0.5 BRASS INSERTS |  |  |  | Brass Heat-Set Inserts for Plastic; M3 x 0.50 mm Thread Size, 5.700 mm Installed Length |  |  | MCMASTER | 94459A140 | https://www.mcmaster.com/94459A140-94459A140 | 4 |  |  | 4 | 0
REAR ACCELEROMETER UNIT | - | SCREW; PHILLIPS; M3X0.5X6 |  |  |  | Stainless Steel Pan Head Screws; with External-Tooth Washer, M3 x 0.5 mm Thread, 6 mm Long |  |  | MCMASTER | 90317A523 | https://www.mcmaster.com/90317A523-90317A523 | 4 |  |  | 4 | 0
REAR ACCELEROMETER UNIT | - | 1/4" WASHER |  |  |  | 316 Stainless Steel Washer; for 1/4" Screw Size, 0.281" ID, 0.625" OD |  |  | MCMASTER | 90107A029 | https://www.mcmaster.com/90107A029-90107A029 | 4 |  |  | 4 | 0
 |  |  |  |  |  |  |  |  |  |  |  |  |  |  | 0 | 0
 |  |  |  |  |  |  |  |  |  |  |  |  |  |  | 0 | 0
 |  |  |  |  |  |  |  |  |  |  |  |  |  |  | 0 | 0
 |  |  |  |  |  |  |  |  |  |  |  |  |  |  | 0 | 0
 |  |  |  |  |  |  |  |  |  |  |  |  |  |  | 0 | 0
 |  |  |  |  |  |  |  |  |  |  |  |  |  |  | 0 | 0
 |  |  |  |  |  |  |  |  |  |  |  |  |  |  | 0 | 0
 |  |  |  |  |  |  |  |  |  |  |  |  |  |  | 0 | 0
 |  |  |  |  |  |  |  |  |  |  |  |  |  |  | 0 | 0
 |  |  |  |  |  |  |  |  |  |  |  |  |  |  | 0 | 0
 |  |  |  |  |  |  |  |  |  |  |  |  |  |  | 0 | 0
 |  |  |  |  |  |  |  |  |  |  |  |  |  |  | 0 | 0
 |  |  |  |  |  |  |  |  |  |  |  |  |  |  | 0 | 0
 |  |  |  |  |  |  |  |  |  |  |  |  |  |  | 0 | 0
 |  |  |  |  |  |  |  |  |  |  |  |  |  |  | 0 | 0
 |  |  |  |  |  |  |  |  |  |  |  |  |  |  | 0 | 0
 |  |  |  |  |  |  |  |  |  |  |  |  |  |  | 0 | 0
 |  |  |  |  |  |  |  |  |  |  |  |  |  |  | 0 | 0
 |  |  |  |  |  |  |  |  |  |  |  |  |  |  | 0 | 0
 |  |  |  |  |  |  |  |  |  |  |  |  |  |  | 0 | 0
 |  |  |  |  |  |  |  |  |  |  |  |  |  |  | 0 | 0
 |  |  |  |  |  |  |  |  |  |  |  |  |  |  | 0 | 0
 |  |  |  |  |  |  |  |  |  |  |  |  |  |  | 0 | 0
 |  |  |  |  |  |  |  |  |  |  |  |  |  |  | 0 | 0
 |  |  |  |  |  |  |  |  |  |  |  |  |  |  | 0 | 0
 |  |  |  |  |  |  |  |  |  |  |  |  |  |  | 0 | 0
 |  |  |  |  |  |  |  |  |  |  |  |  |  |  | 0 | 0
 |  |  |  |  |  |  |  |  |  |  |  |  |  |  | 0 | 0
 |  |  |  |  |  |  |  |  |  |  |  |  |  |  | 0 | 0
 |  |  |  |  |  |  |  |  |  |  |  |  |  |  | 0 | 0
 |  |  |  |  |  |  |  |  |  |  |  |  |  |  | 0 | 0
 |  |  |  |  |  |  |  |  |  |  |  |  |  |  | 0 | 0
 |  |  |  |  |  |  |  |  |  |  |  |  |  |  | 0 | 0
 |  |  |  |  |  |  |  |  |  |  |  |  |  |  | 0 | 0
 |  |  |  |  |  |  |  |  |  |  |  |  |  |  | 0 | 0
 |  |  |  |  |  |  |  |  |  |  |  |  |  |  | 0 | 0
 |  |  |  |  |  |  |  |  |  |  |  |  |  |  | 0 | 0
 |  |  |  |  |  |  |  |  |  |  |  |  |  |  | 0 | 0
 |  |  |  |  |  |  |  |  |  |  |  |  |  |  | 0 | 0
 |  |  |  |  |  |  |  |  |  |  |  |  |  |  | 0 | 0
 |  |  |  |  |  |  |  |  |  |  |  |  |  |  | 0 | 0
 |  |  |  |  |  |  |  |  |  |  |  |  |  |  | 0 | 0
 |  |  |  |  |  |  |  |  |  |  |  |  |  |  | 0 | 0
 |  |  |  |  |  |  |  |  |  |  |  |  |  |  | 0 | 0
 |  |  |  |  |  |  |  |  |  |  |  |  |  |  | 0 | 0
 |  |  |  |  |  |  |  |  |  |  |  |  |  |  | 0 | 0
 |  |  |  |  |  |  |  |  |  |  |  |  |  |  | 0 | 0
 |  |  |  |  |  |  |  |  |  |  |  |  |  |  | 0 | 0
 |  |  |  |  |  |  |  |  |  |  |  |  |  |  | 0 | 0
 |  |  |  |  |  |  |  |  |  |  |  |  |  |  | 0 | 0
 |  |  |  |  |  |  |  |  |  |  |  |  |  |  | 0 | 0
 |  |  |  |  |  |  |  |  |  |  |  |  |  |  | 0 | 0
 |  |  |  |  |  |  |  |  |  |  |  |  |  |  | 0 | 0
 |  |  |  |  |  |  |  |  |  |  |  |  |  |  | 0 | 0
 |  |  |  |  |  |  |  |  |  |  |  |  |  |  | 0 | 0
 |  |  |  |  |  |  |  |  |  |  |  |  |  |  | 0 | 0
 |  |  |  |  |  |  |  |  |  |  |  |  |  |  | 0 | 0
 |  |  |  |  |  |  |  |  |  |  |  |  |  |  | 0 | 0
 |  |  |  |  |  |  |  |  |  |  |  |  |  |  | 0 | 0
 |  |  |  |  |  |  |  |  |  |  |  |  |  |  | 0 | 0
 |  |  |  |  |  |  |  |  |  |  |  |  |  |  | 0 | 0
 |  |  |  |  |  |  |  |  |  |  |  |  |  |  | 0 | 0
 |  |  |  |  |  |  |  |  |  |  |  |  |  |  | 0 | 0
 |  |  |  |  |  |  |  |  |  |  |  |  |  |  | 0 | 0
 |  |  |  |  |  |  |  |  |  |  |  |  |  |  | 0 | 0
 |  |  |  |  |  |  |  |  |  |  |  |  |  |  | 0 | 0
 |  |  |  |  |  |  |  |  |  |  |  |  |  |  | 0 | 0
 |  |  |  |  |  |  |  |  |  |  |  |  |  |  | 0 | 0
 |  |  |  |  |  |  |  |  |  |  |  |  |  |  | 0 | 0
 |  |  |  |  |  |  |  |  |  |  |  |  |  |  | 0 | 0
 |  |  |  |  |  |  |  |  |  |  |  |  |  |  | 0 | 0
 |  |  |  |  |  |  |  |  |  |  |  |  |  |  | 0 | 0
 |  |  |  |  |  |  |  |  |  |  |  |  |  |  | 0 | 0
 |  |  |  |  |  |  |  |  |  |  |  |  |  |  | 0 | 0
 |  |  |  |  |  |  |  |  |  |  |  |  |  |  | 0 | 0
 |  |  |  |  |  |  |  |  |  |  |  |  |  |  | 0 | 0
 |  |  |  |  |  |  |  |  |  |  |  |  |  |  | 0 | 0
 |  |  |  |  |  |  |  |  |  |  |  |  |  |  | 0 | 0
 |  |  |  |  |  |  |  |  |  |  |  |  |  |  | 0 | 0
 |  |  |  |  |  |  |  |  |  |  |  |  |  |  |  | 0
 |  |  |  |  |  |  |  |  |  |  |  |  |  |  |  | 0
 |  |  |  |  |  |  |  |  |  |  |  |  |  |  |  | 0
 |  |  |  |  |  |  |  |  |  |  |  |  |  |  |  | 0
 |  |  |  |  |  |  |  |  |  |  |  |  |  |  |  | 0
 |  |  |  |  |  |  |  |  |  |  |  |  |  |  |  | 0
 |  |  |  |  |  |  |  |  |  |  |  |  |  |  |  | 0
 |  |  |  |  |  |  |  |  |  |  |  |  |  |  |  | 0
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

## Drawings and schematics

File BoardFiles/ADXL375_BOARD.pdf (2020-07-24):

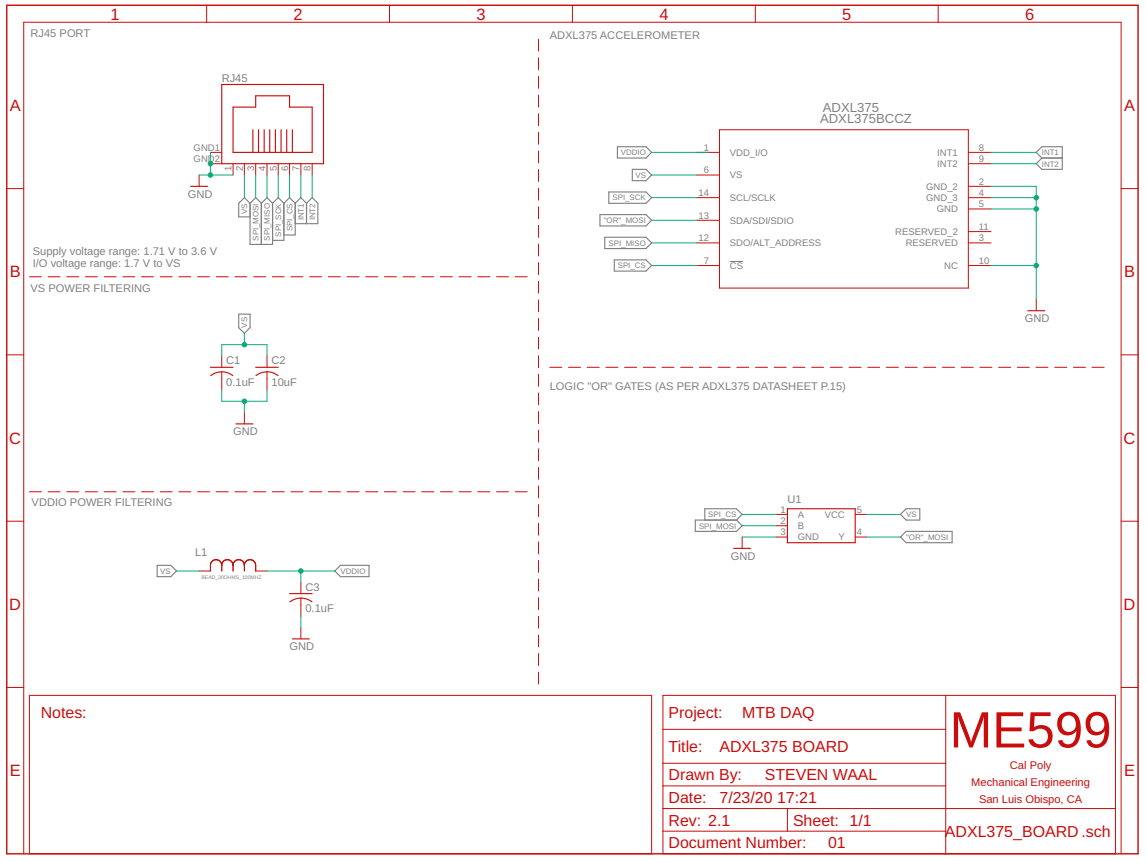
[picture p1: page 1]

Supply voltage range: 1.71 V to 3.6 V
I/O voltage range: 1.7 V to VS
VS POWER FILTERING

LOGIC "OR" GATES (AS PER ADXL375 DATASHEET P.15)

Mechanical Engineering
San Luis Obispo, CA
ADXL375_BOARD

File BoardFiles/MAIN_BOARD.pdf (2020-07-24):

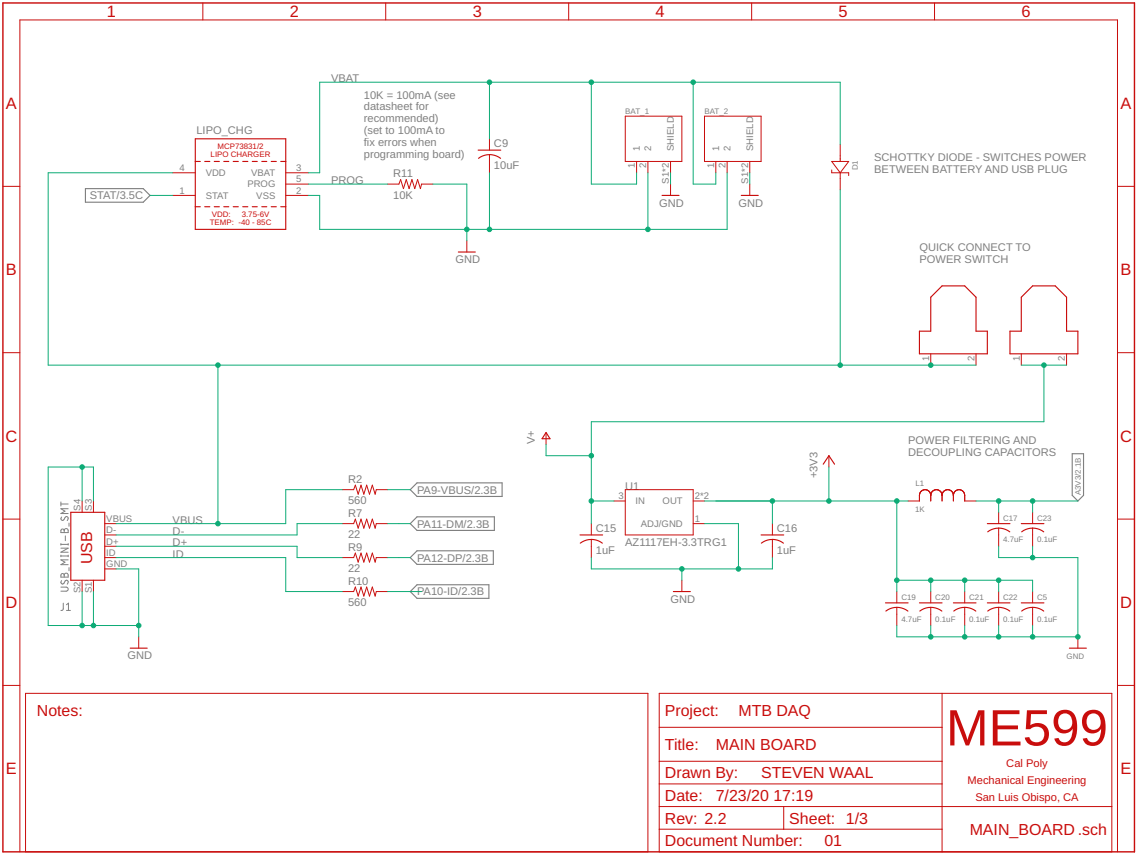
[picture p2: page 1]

BETWEEN BATTERY AND USB PLUG

Mechanical Engineering
San Luis Obispo, CA
MAIN_BOARD

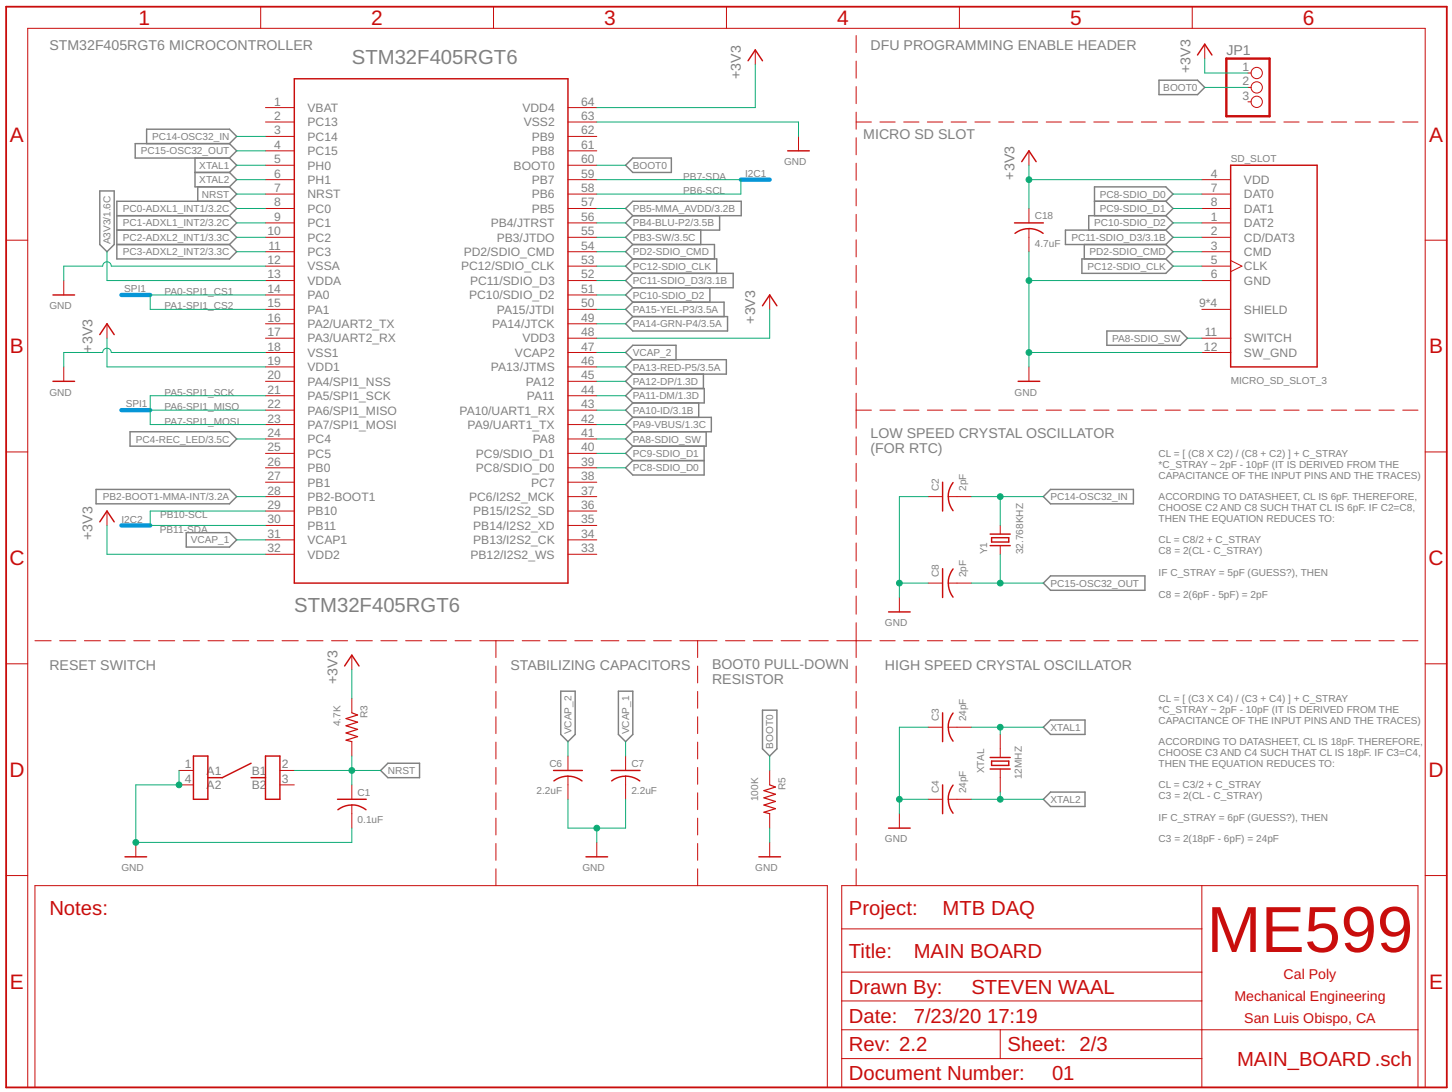
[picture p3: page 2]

DFU PROGRAMMING ENABLE HEADER

LOW SPEED CRYSTAL OSCILLATOR
(FOR RTC)

CL = [ (C8 X C2) / (C8 + C2) ] + C_STRAY
*C_STRAY ~ 2pF - 10pF (IT IS DERIVED FROM THE CAPACITANCE OF THE INPUT PINS AND THE TRACES) ACCORDING TO DATASHEET, CL IS 6pF. THEREFORE, CHOOSE C2 AND C8 SUCH THAT CL IS 6pF. IF C2=C8, THEN THE EQUATION REDUCES TO: CL = C8/2 + C_STRAY C8 = 2(CL - C_STRAY)

HIGH SPEED CRYSTAL OSCILLATOR

CL = [ (C3 X C4) / (C3 + C4) ] + C_STRAY
*C_STRAY ~ 2pF - 10pF (IT IS DERIVED FROM THE CAPACITANCE OF THE INPUT PINS AND THE TRACES) ACCORDING TO DATASHEET, CL IS 18pF. THEREFORE, CHOOSE C3 AND C4 SUCH THAT CL IS 18pF. IF C3=C4, THEN THE EQUATION REDUCES TO: CL = C3/2 + C_STRAY C3 = 2(CL - C_STRAY)

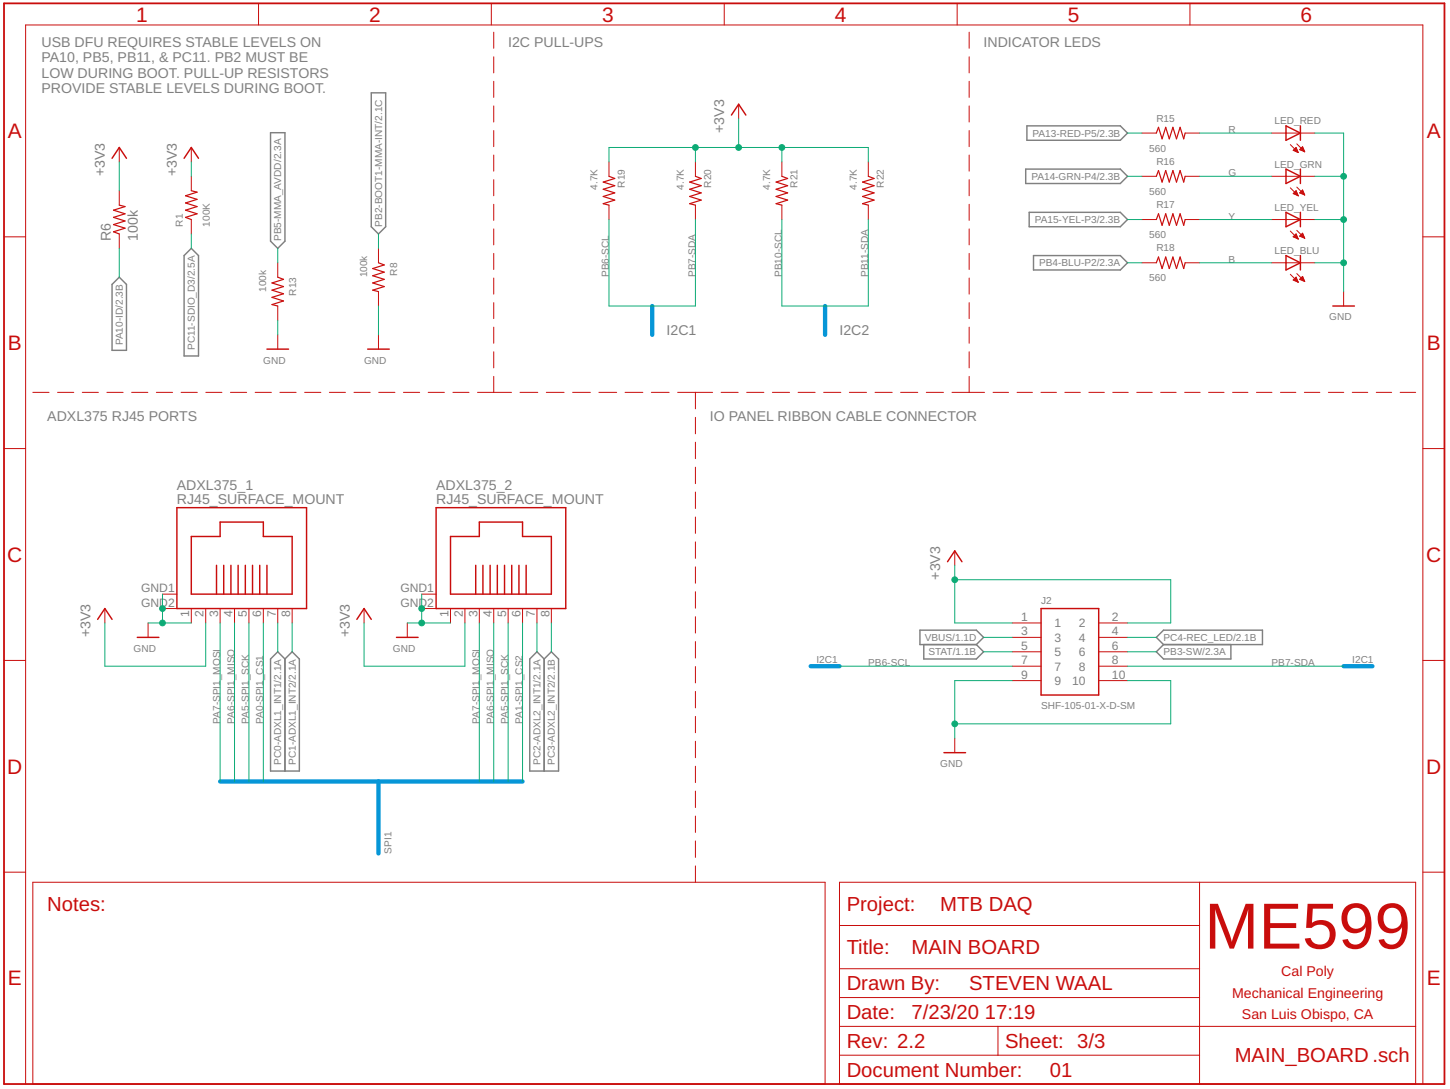
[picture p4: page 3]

PA10, PB5, PB11, & PC11. PB2 MUST BE
LOW DURING BOOT. PULL-UP RESISTORS
PROVIDE STABLE LEVELS DURING BOOT.

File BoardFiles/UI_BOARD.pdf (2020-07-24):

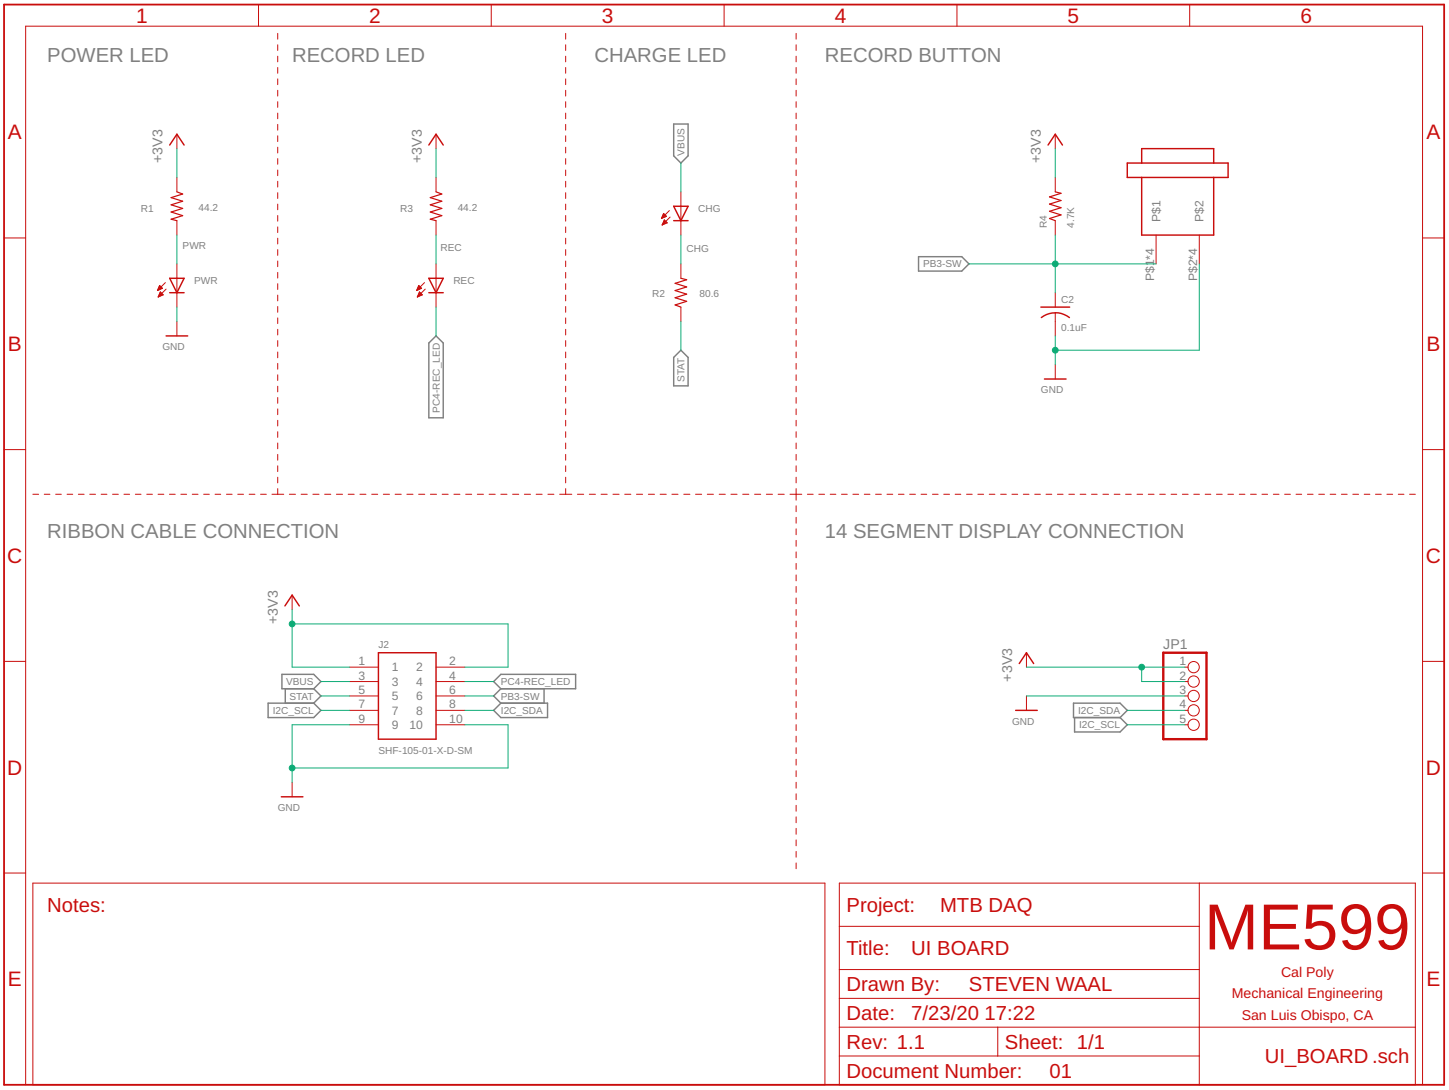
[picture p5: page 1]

Mechanical Engineering
San Luis Obispo, CA
UI_BOARD

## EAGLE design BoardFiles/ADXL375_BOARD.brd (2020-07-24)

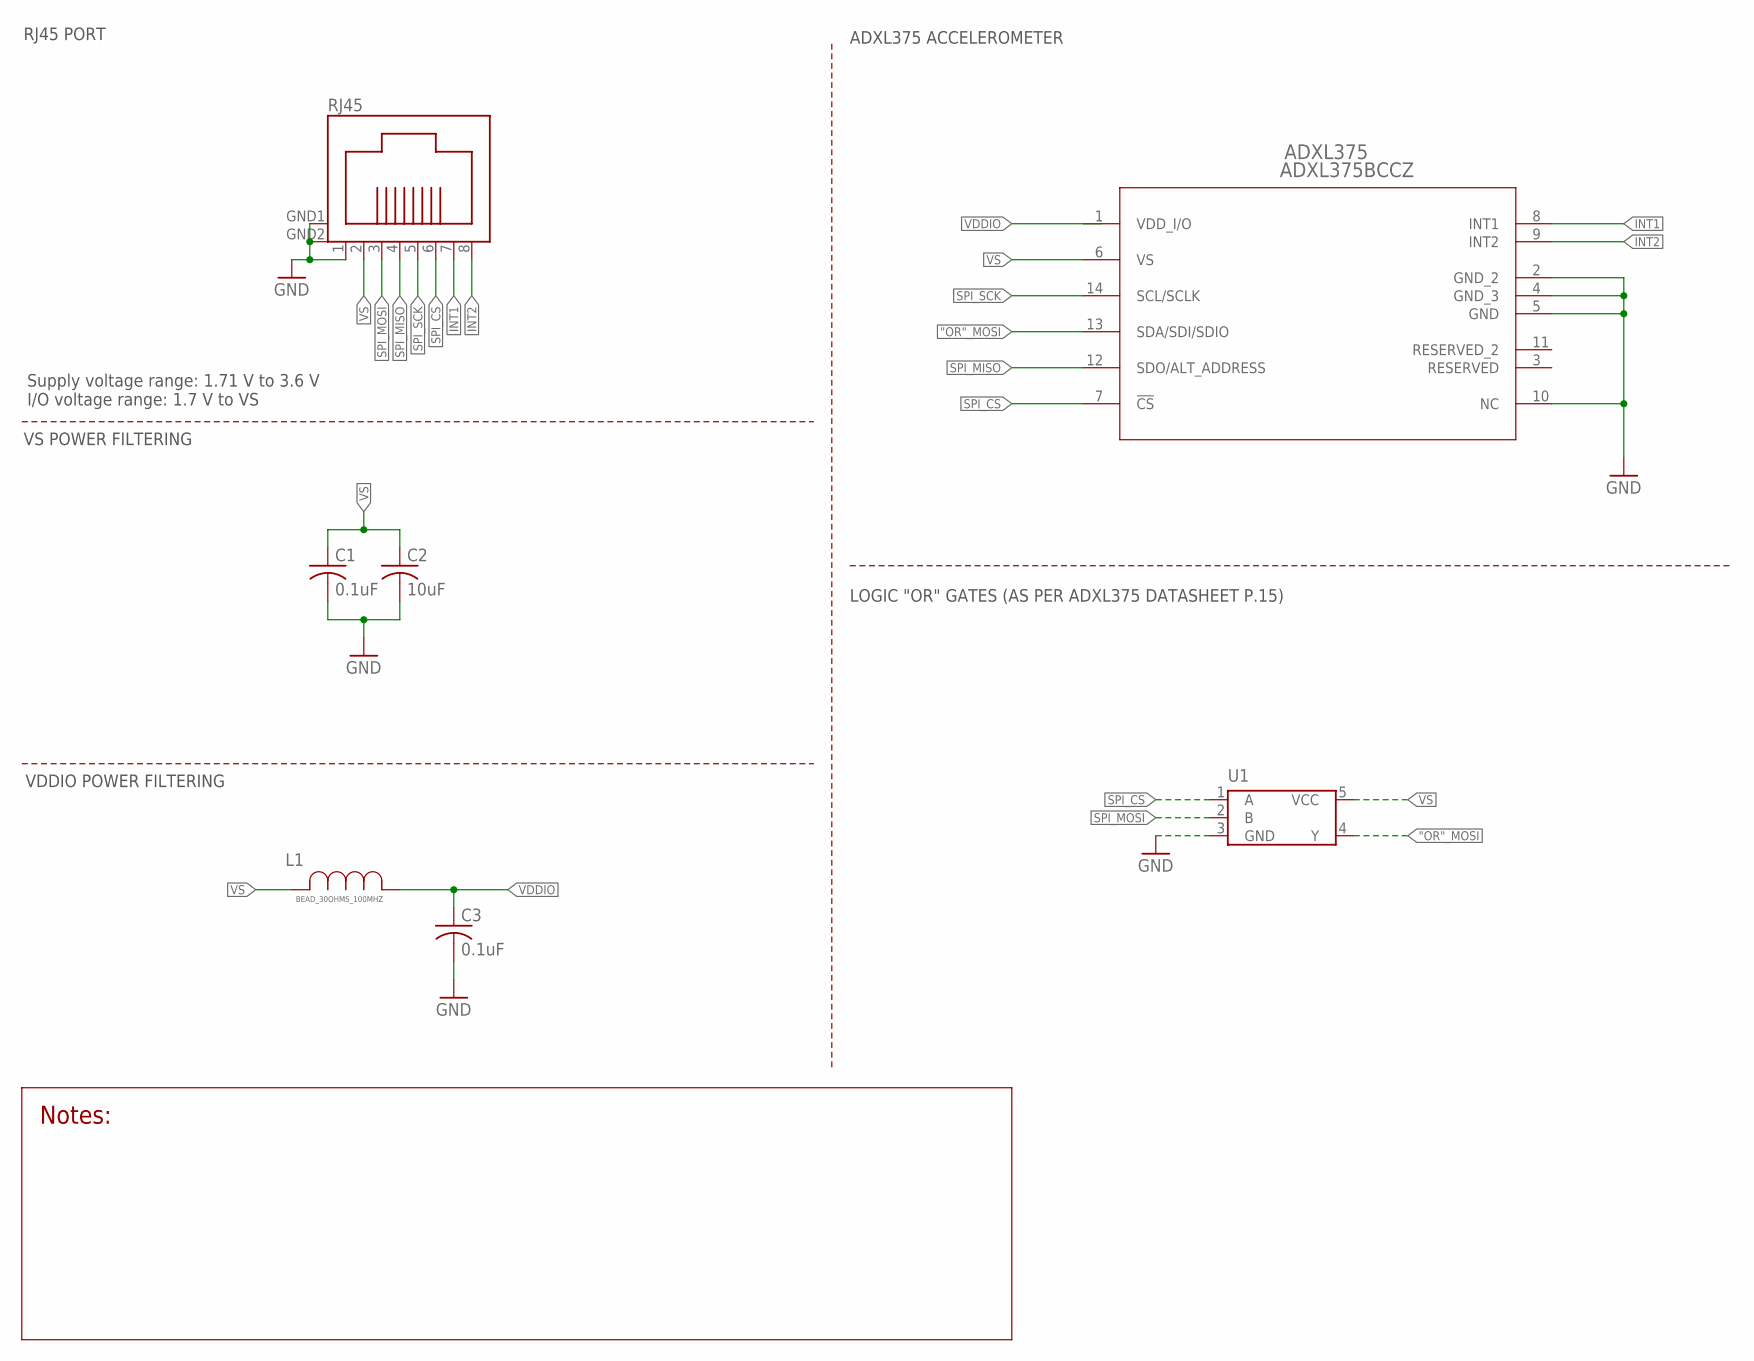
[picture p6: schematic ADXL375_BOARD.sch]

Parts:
ADXL375: ADXL375BCCZ; LGA_CC-14-1
C1, C3: 0.1uF; C0805
C2: 10uF; C0805
L1: BEAD_30OHMS_100MHZ; IND_BOURNS_MH2029
RJ45: RJ45_SURFACE_MOUNT
U1: SN74LVC1G32DCKR; DCK5

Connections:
"OR"_MOSI: ADXL375.13 (SDA/SDI/SDIO), U1.4 (Y)
GND: ADXL375.2 (GND_2), ADXL375.4 (GND_3), ADXL375.5 (GND), ADXL375.10 (NC), C1.2, C2.2, C3.2, RJ45.1, RJ45.GND1, RJ45.GND2, U1.3 (GND)
INT1: ADXL375.8 (INT1), RJ45.7
INT2: ADXL375.9 (INT2), RJ45.8
SPI_CS: ADXL375.7 (!CS), RJ45.6, U1.1 (A)
SPI_MISO: ADXL375.12 (SDO/ALT_ADDRESS), RJ45.4
SPI_MOSI: RJ45.3, U1.2 (B)
SPI_SCK: ADXL375.14 (SCL/SCLK), RJ45.5
VDDIO: ADXL375.1 (VDD_I/O), C3.1, L1.1
VS: ADXL375.6 (VS), C1.1, C2.1, L1.2, RJ45.2, U1.5 (VCC)

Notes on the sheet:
Supply voltage range: 1.71 V to 3.6 V I/O voltage range: 1.7 V to VS
RJ45 PORT
VS POWER FILTERING
VDDIO POWER FILTERING
LOGIC "OR" GATES (AS PER ADXL375 DATASHEET P.15)
ADXL375 ACCELEROMETER

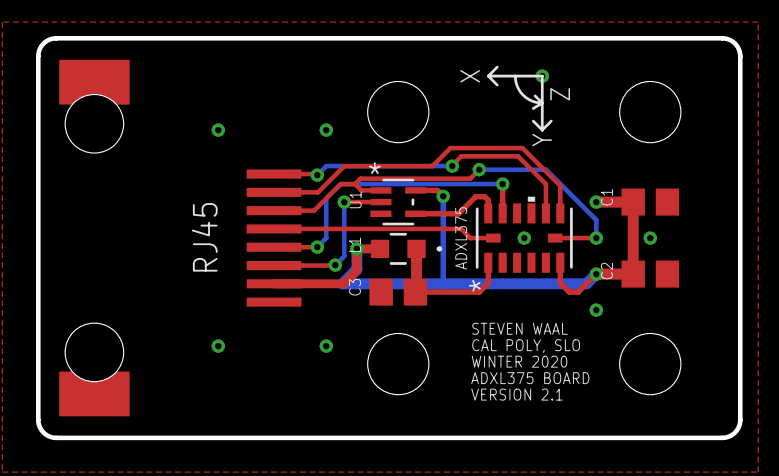
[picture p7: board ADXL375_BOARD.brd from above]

Board: 2 copper layers, 39.0 x 22.2 mm, 7 parts (0 on the bottom side), 10 nets.

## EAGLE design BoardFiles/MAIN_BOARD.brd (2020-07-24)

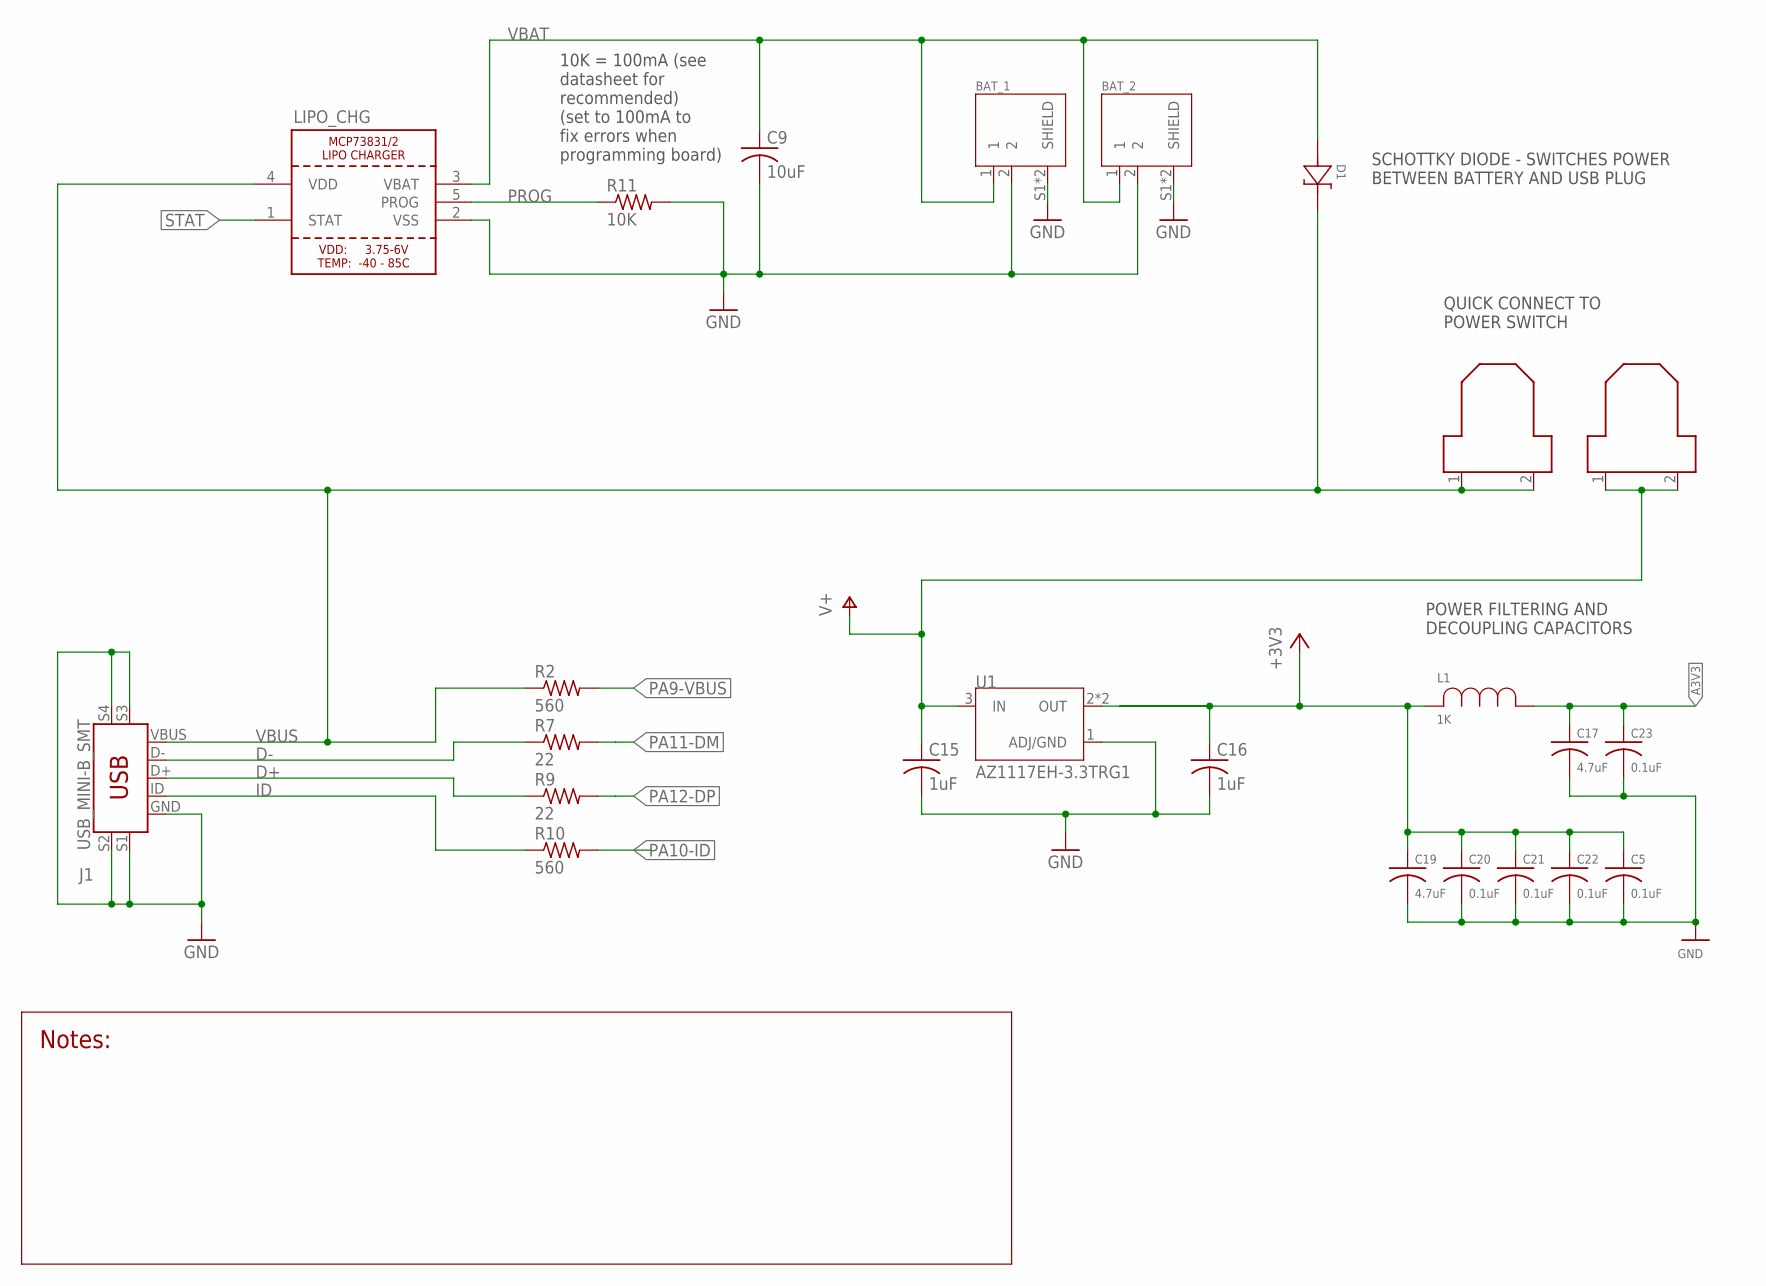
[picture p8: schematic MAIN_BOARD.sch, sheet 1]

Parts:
(+): QUICK_CONNECT_0.187"
(-): QUICK_CONNECT_0.187"
BAT_1, BAT_2: S2B-PH-SM4-TB(LF)(SN); JST_S2B-PH-SM4-TB(LF)(SN)
C5, C20, C21, C22, C23: 0.1uF; C0805
C9: 10uF; C0805
C15, C16: 1uF; C0805
C17, C19: 4.7uF; C0805
D1: DIODE_SCHOTTKY; DIODE_SOD123W_1P9X2P8
J1: USB_MINI-B_SMT; USB-MINIB
L1: 1K; IND_VISHAY_ILHB0805
LIPO_CHG: LIPO_CHARGER_MCP73831/2; SOT23-5
R2, R10: 560; R0805
R7, R9: 22; R0805
R11: 10K; R0805
U1: AZ1117EH-3.3TRG1; SOT230P700X180-4N

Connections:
+3V3: C5.1, C16.1, C19.1, C20.1, C21.1, C22.1, L1.2, U1.2 (OUT), U1.4 (OUT); also elsewhere on the board
A3V3: C17.1, C23.1, L1.1; also elsewhere on the board
D+: J1.D+, R9.1
D-: J1.D-, R7.1
GND: BAT_1.2, BAT_1.S1 (SHIELD), BAT_1.S2 (SHIELD), BAT_2.2, BAT_2.S1 (SHIELD), BAT_2.S2 (SHIELD), C5.2, C9.2, C15.2, C16.2, C17.2, C19.2, C20.2, C21.2, C22.2, C23.2, J1.GND, J1.S1 (SHIELD), J1.S2 (SHIELD1), J1.S3 (SHIELD2), J1.S4 (SHIELD3), LIPO_CHG.2 (VSS), R11.2, U1.1 (ADJ/GND); also elsewhere on the board
ID: J1.ID, R10.1
PA9-VBUS: R2.2; also elsewhere on the board
PA10-ID: R10.2; also elsewhere on the board
PA11-DM: R7.2; also elsewhere on the board
PA12-DP: R9.2; also elsewhere on the board
PROG: LIPO_CHG.5 (PROG), R11.1
STAT: LIPO_CHG.1 (STAT); also elsewhere on the board
V+: (-).1, (-).2, C15.1, U1.3 (IN)
VBAT: BAT_1.1, BAT_2.1, C9.1, D1.2, LIPO_CHG.3 (VBAT)
VBUS: (+).1, (+).2, D1.1, J1.VBUS, LIPO_CHG.4 (VDD), R2.1; also elsewhere on the board

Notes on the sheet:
10K = 100mA (see datasheet for recommended) (set to 100mA to fix errors when programming board)
SCHOTTKY DIODE - SWITCHES POWER BETWEEN BATTERY AND USB PLUG
POWER FILTERING AND DECOUPLING CAPACITORS
QUICK CONNECT TO POWER SWITCH

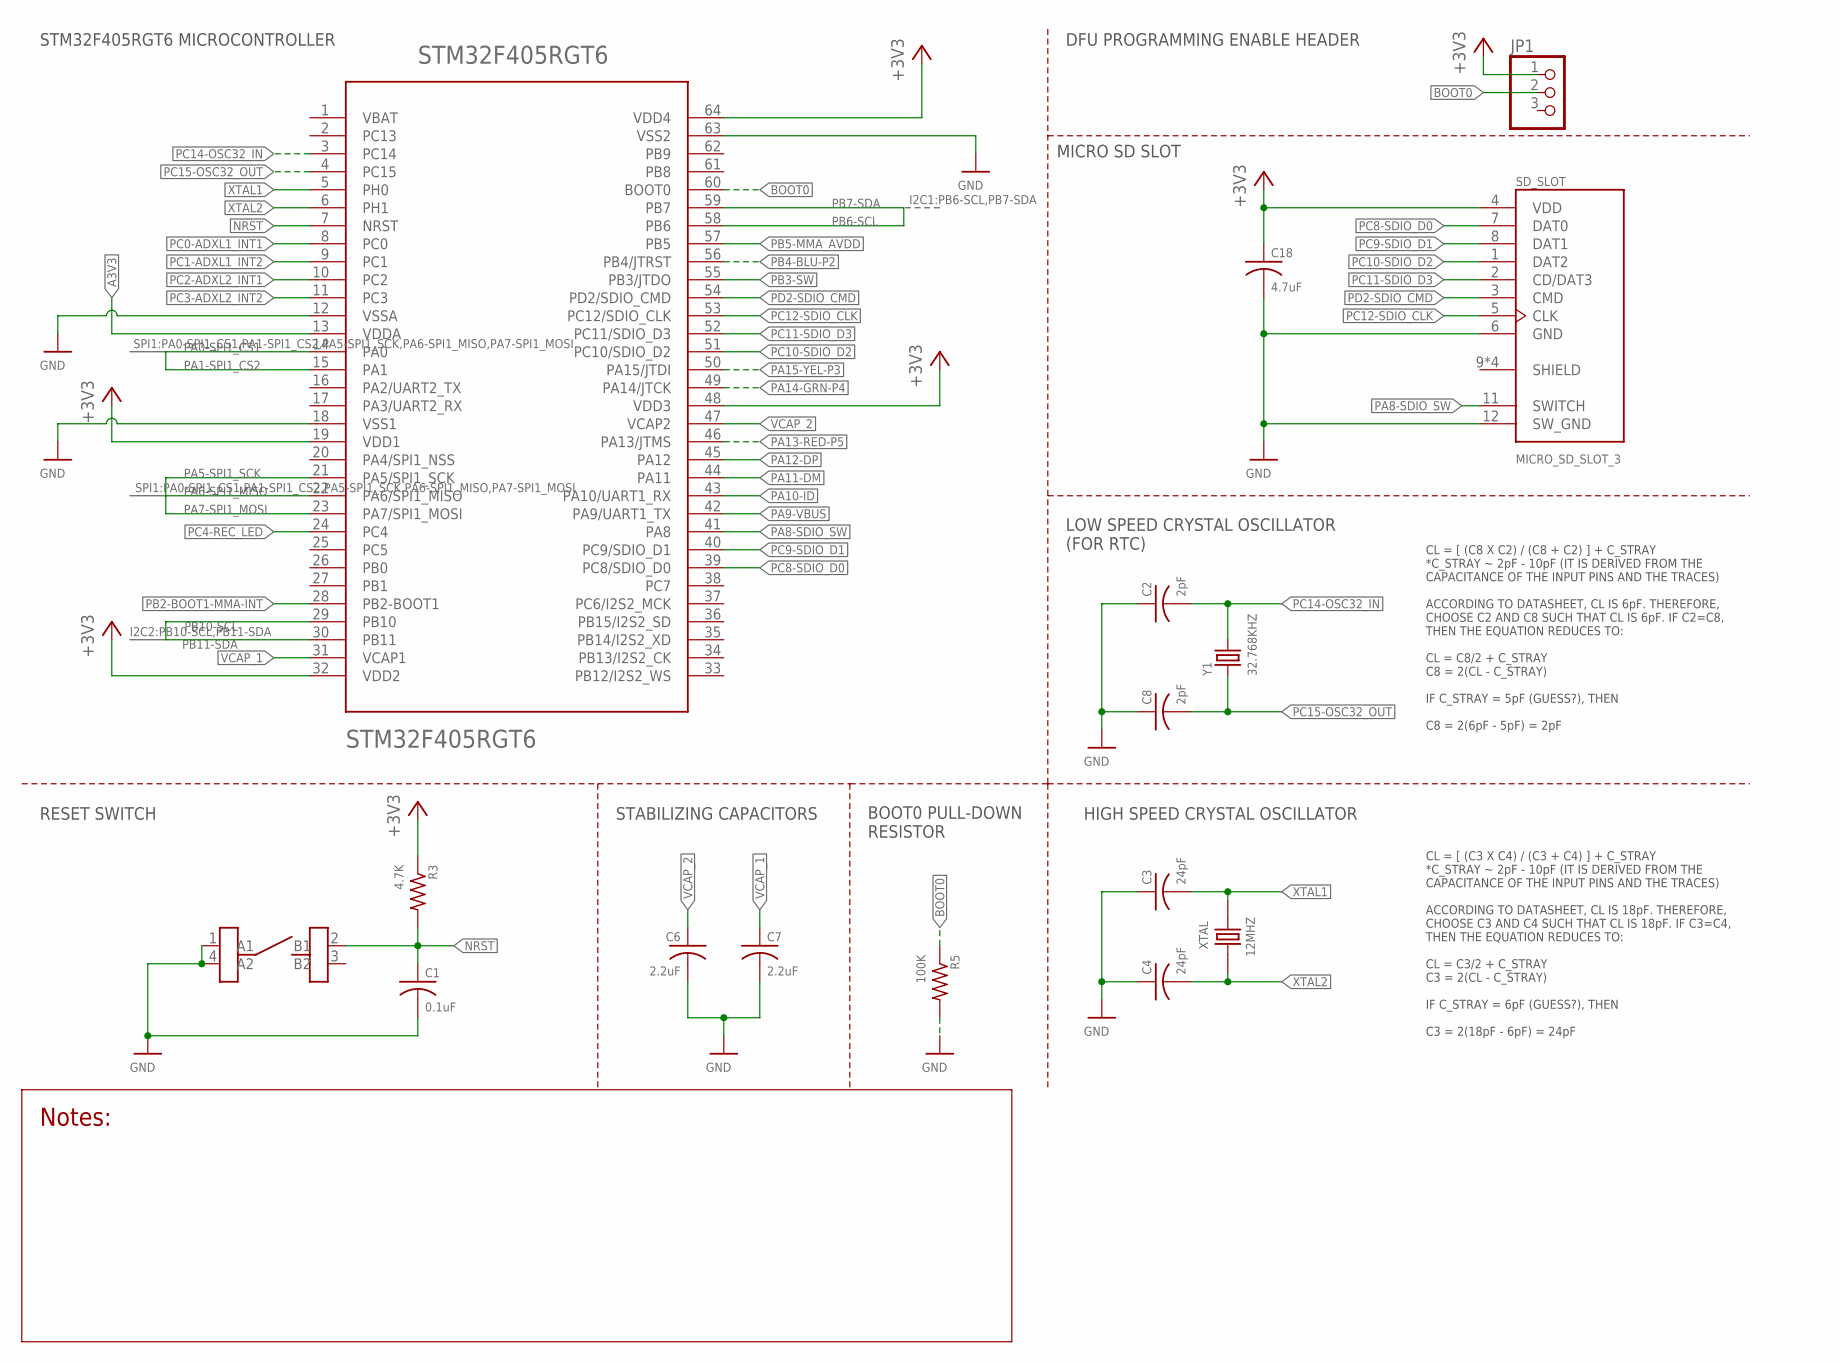
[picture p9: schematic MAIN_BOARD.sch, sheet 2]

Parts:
C1: 0.1uF; C0805
C2, C8: 2pF; C0805
C3, C4: 24pF; C0805
C6, C7: 2.2uF; C0805
C18: 4.7uF; C0805
JP1: PINHD-1X3; 1X03
R3: 4.7K; R0805
R5: 100K; R0805
RESET: SWITCH; SWITCH_FSM6JSMATR
SD_SLOT: MICRO_SD_SLOT_3; CON00218_8
STM32F405RGT6: STM32F405RGT6; TQFP64
XTAL: 12MHZ; XTAL_ECS-120-18-5PX-TR
Y1: 32.768KHZ; XTAL_ABS25-32.768KHZ-6-1-T

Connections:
+3V3: C18.1, JP1.1, R3.1, SD_SLOT.4 (VDD), STM32F405RGT6.19 (VDD1), STM32F405RGT6.32 (VDD2), STM32F405RGT6.48 (VDD3), STM32F405RGT6.64 (VDD4); also elsewhere on the board
A3V3: STM32F405RGT6.13 (VDDA); also elsewhere on the board
BOOT0: JP1.2, R5.1, STM32F405RGT6.60 (BOOT0)
GND: C1.2, C2.1, C3.1, C4.1, C6.2, C7.2, C8.1, C18.2, R5.2, RESET.1 (A1), RESET.4 (A2), SD_SLOT.6 (GND), SD_SLOT.12 (SW_GND), STM32F405RGT6.12 (VSSA), STM32F405RGT6.18 (VSS1), STM32F405RGT6.63 (VSS2); also elsewhere on the board
NRST: C1.1, R3.2, RESET.2 (B1), STM32F405RGT6.7 (NRST)
PA0-SPI1_CS1: STM32F405RGT6.14 (PA0); also elsewhere on the board
PA1-SPI1_CS2: STM32F405RGT6.15 (PA1); also elsewhere on the board
PA5-SPI1_SCK: STM32F405RGT6.21 (PA5/SPI1_SCK); also elsewhere on the board
PA6-SPI1_MISO: STM32F405RGT6.22 (PA6/SPI1_MISO); also elsewhere on the board
PA7-SPI1_MOSI: STM32F405RGT6.23 (PA7/SPI1_MOSI); also elsewhere on the board
PA8-SDIO_SW: SD_SLOT.11 (SWITCH), STM32F405RGT6.41 (PA8)
PA9-VBUS: STM32F405RGT6.42 (PA9/UART1_TX); also elsewhere on the board
PA10-ID: STM32F405RGT6.43 (PA10/UART1_RX); also elsewhere on the board
PA11-DM: STM32F405RGT6.44 (PA11); also elsewhere on the board
PA12-DP: STM32F405RGT6.45 (PA12); also elsewhere on the board
PA13-RED-P5: STM32F405RGT6.46 (PA13/JTMS); also elsewhere on the board
PA14-GRN-P4: STM32F405RGT6.49 (PA14/JTCK); also elsewhere on the board
PA15-YEL-P3: STM32F405RGT6.50 (PA15/JTDI); also elsewhere on the board
PB2-BOOT1-MMA-INT: STM32F405RGT6.28 (PB2-BOOT1); also elsewhere on the board
PB3-SW: STM32F405RGT6.55 (PB3/JTDO); also elsewhere on the board
PB4-BLU-P2: STM32F405RGT6.56 (PB4/JTRST); also elsewhere on the board
PB5-MMA_AVDD: STM32F405RGT6.57 (PB5); also elsewhere on the board
PB6-SCL: STM32F405RGT6.58 (PB6); also elsewhere on the board
PB7-SDA: STM32F405RGT6.59 (PB7); also elsewhere on the board
PB10-SCL: STM32F405RGT6.29 (PB10); also elsewhere on the board
PB11-SDA: STM32F405RGT6.30 (PB11); also elsewhere on the board
PC0-ADXL1_INT1: STM32F405RGT6.8 (PC0); also elsewhere on the board
PC1-ADXL1_INT2: STM32F405RGT6.9 (PC1); also elsewhere on the board
PC2-ADXL2_INT1: STM32F405RGT6.10 (PC2); also elsewhere on the board
PC3-ADXL2_INT2: STM32F405RGT6.11 (PC3); also elsewhere on the board
PC4-REC_LED: STM32F405RGT6.24 (PC4); also elsewhere on the board
PC8-SDIO_D0: SD_SLOT.7 (DAT0), STM32F405RGT6.39 (PC8/SDIO_D0)
PC9-SDIO_D1: SD_SLOT.8 (DAT1), STM32F405RGT6.40 (PC9/SDIO_D1)
PC10-SDIO_D2: SD_SLOT.1 (DAT2), STM32F405RGT6.51 (PC10/SDIO_D2)
PC11-SDIO_D3: SD_SLOT.2 (CD/DAT3), STM32F405RGT6.52 (PC11/SDIO_D3); also elsewhere on the board
PC12-SDIO_CLK: SD_SLOT.5 (CLK), STM32F405RGT6.53 (PC12/SDIO_CLK)
PC14-OSC32_IN: C2.2, STM32F405RGT6.3 (PC14), Y1.4 (2)
PC15-OSC32_OUT: C8.2, STM32F405RGT6.4 (PC15), Y1.1
PD2-SDIO_CMD: SD_SLOT.3 (CMD), STM32F405RGT6.54 (PD2/SDIO_CMD)
VCAP_1: C7.1, STM32F405RGT6.31 (VCAP1)
VCAP_2: C6.1, STM32F405RGT6.47 (VCAP2)
XTAL1: C3.2, STM32F405RGT6.5 (PH0), XTAL.2
XTAL2: C4.2, STM32F405RGT6.6 (PH1), XTAL.1

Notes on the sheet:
STM32F405RGT6 MICROCONTROLLER
RESET SWITCH
STABILIZING CAPACITORS
BOOT0 PULL-DOWN RESISTOR
HIGH SPEED CRYSTAL OSCILLATOR
CL = [ (C3 X C4) / (C3 + C4) ] + C_STRAY *C_STRAY ~ 2pF - 10pF (IT IS DERIVED FROM THE CAPACITANCE OF THE INPUT PINS AND THE TRACES) ACCORDING TO DATASHEET, CL IS 18pF. THEREFORE, CHOOSE C3 AND C4 SUCH THAT CL IS 18pF. IF C3=C4, THEN THE EQUATION REDUCES TO: CL = C3/2 + C_STRAY C3 = 2(CL - C_STRAY)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
CL = [ (C8 X C2) / (C8 + C2) ] + C_STRAY *C_STRAY ~ 2pF - 10pF (IT IS DERIVED FROM THE CAPACITANCE OF THE INPUT PINS AND THE TRACES) ACCORDING TO DATASHEET, CL IS 6pF. THEREFORE, CHOOSE C2 AND C8 SUCH THAT CL IS 6pF. IF C2=C8, THEN THE EQUATION REDUCES TO: CL = C8/2 + C_STRAY C8 = 2(CL - C_STRAY) I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
LOW SPEED CRYSTAL OSCILLATOR (FOR RTC)
MICRO SD SLOT
DFU PROGRAMMING ENABLE HEADER

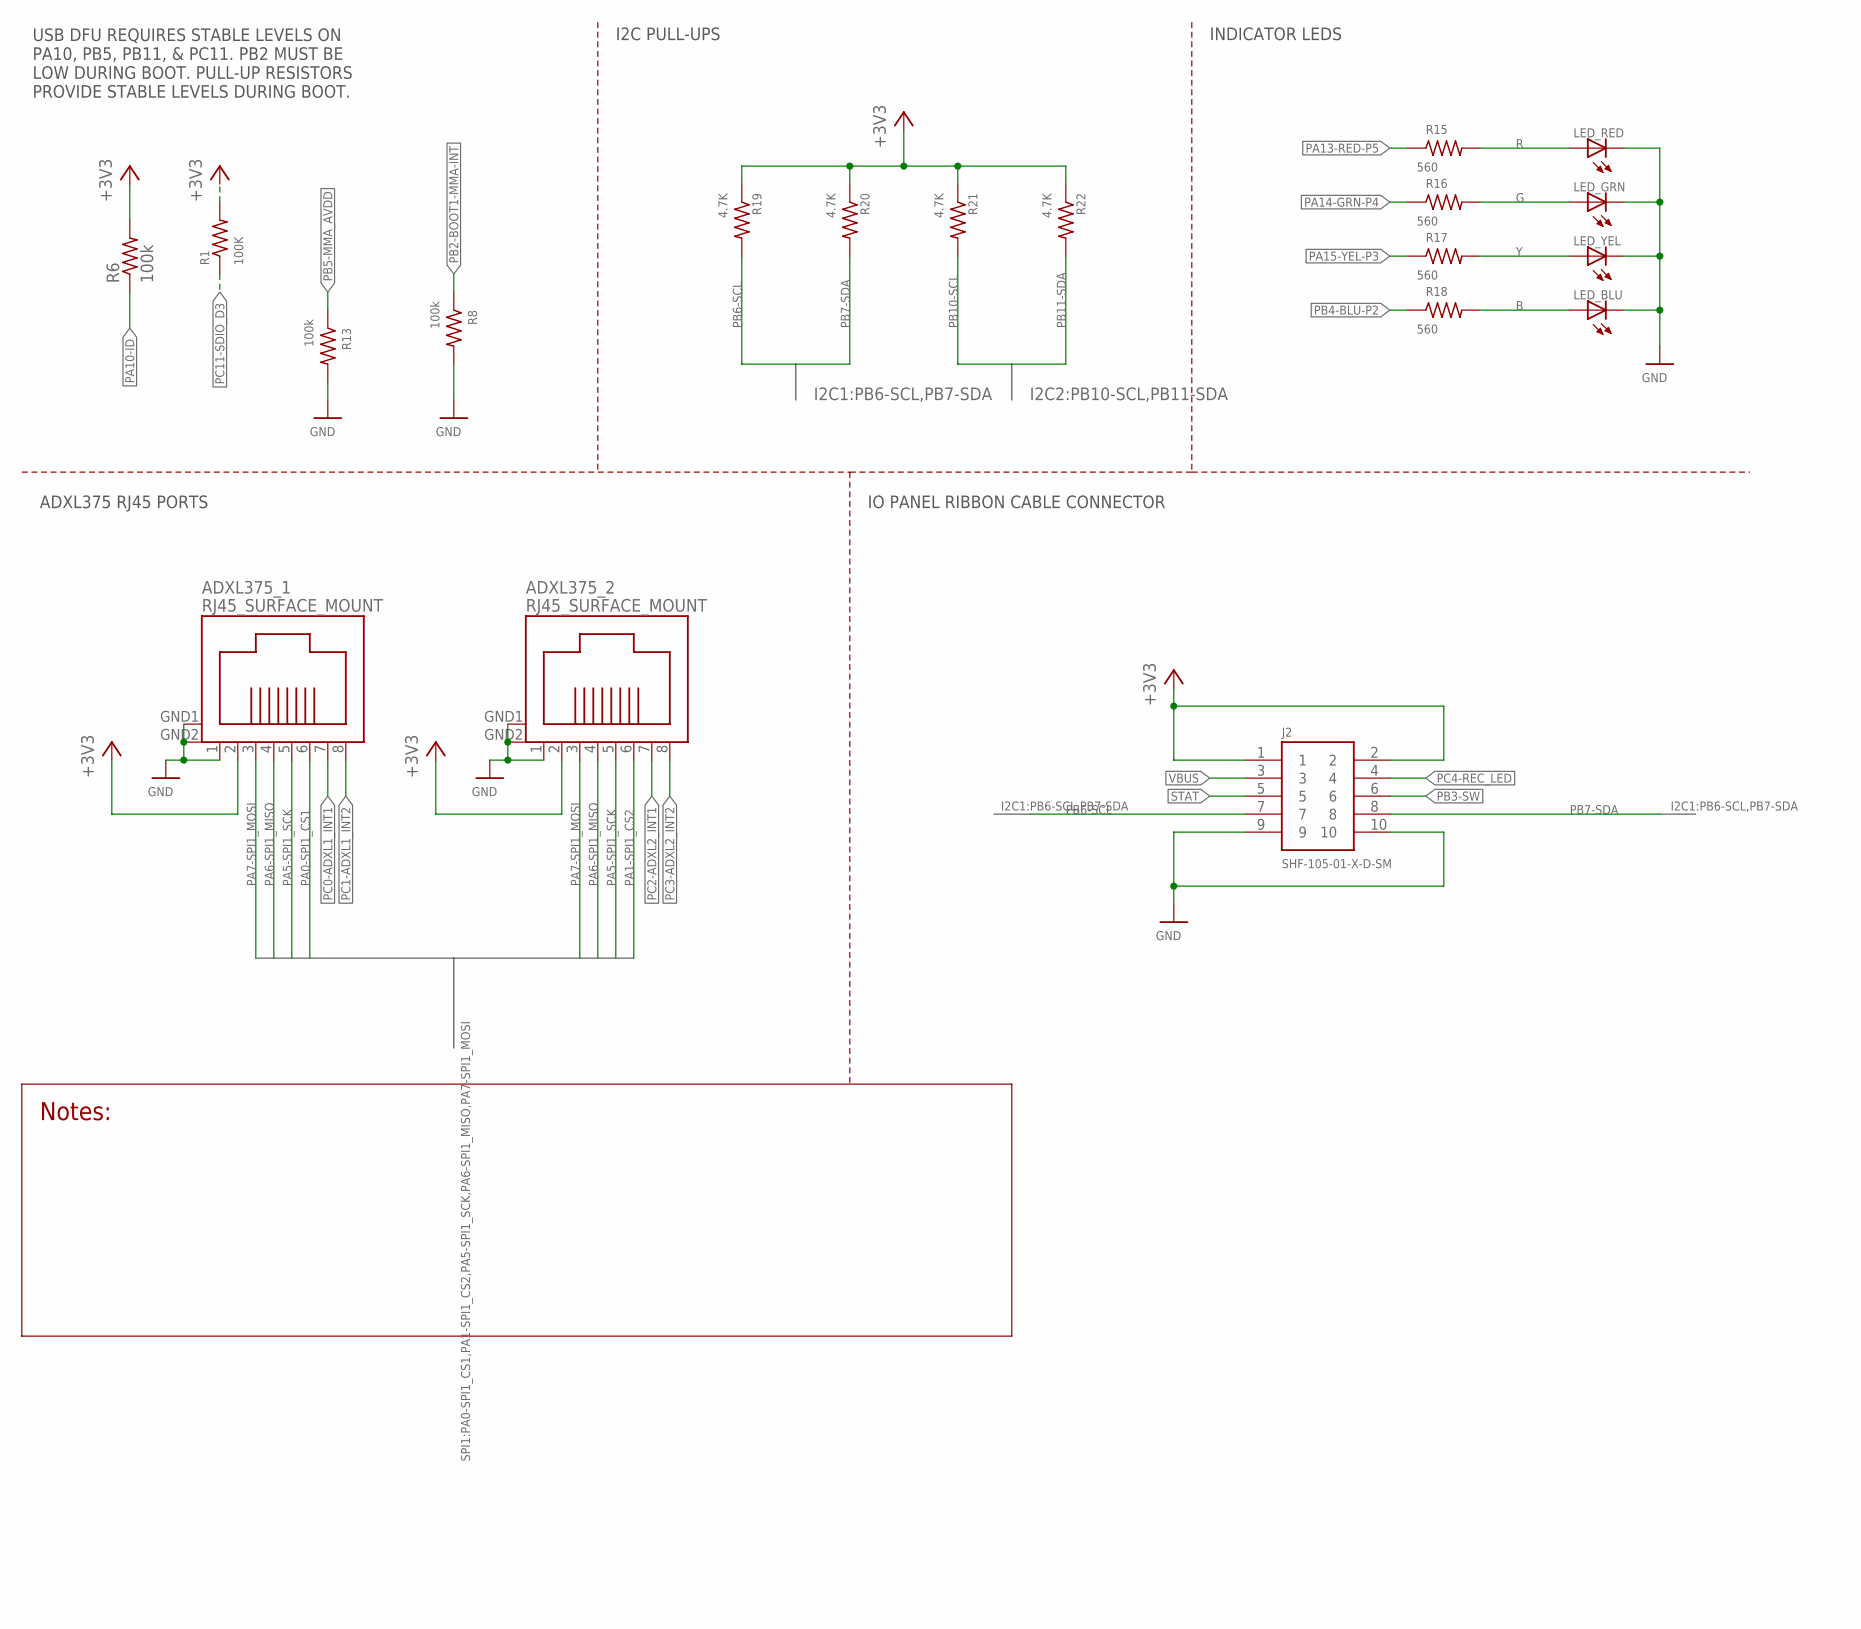
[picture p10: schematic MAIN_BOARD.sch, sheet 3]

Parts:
ADXL375_1, ADXL375_2: RJ45_SURFACE_MOUNT
J2: SHF-105-01-X-D-SM
LED_BLU: LED_0805LED_0805; 0805
LED_GRN: LED_0805LED_0805; 0805
LED_RED: LED_0805LED_0805; 0805
LED_YEL: LED_0805LED_0805; 0805
R1: 100K; R0805
R6, R8, R13: 100k; R0805
R15, R16, R17, R18: 560; R0805
R19, R20, R21, R22: 4.7K; R0805

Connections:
+3V3: ADXL375_1.2, ADXL375_2.2, J2.1, J2.2, R1.2, R6.2, R19.1, R20.1, R21.1, R22.1; also elsewhere on the board
B: LED_BLU.1, R18.2
G: LED_GRN.1, R16.2
GND: ADXL375_1.1, ADXL375_1.GND1, ADXL375_1.GND2, ADXL375_2.1, ADXL375_2.GND1, ADXL375_2.GND2, J2.9, J2.10, LED_BLU.2, LED_GRN.2, LED_RED.2, LED_YEL.2, R8.2, R13.2; also elsewhere on the board
PA0-SPI1_CS1: ADXL375_1.6; also elsewhere on the board
PA1-SPI1_CS2: ADXL375_2.6; also elsewhere on the board
PA5-SPI1_SCK: ADXL375_1.5, ADXL375_2.5; also elsewhere on the board
PA6-SPI1_MISO: ADXL375_1.4, ADXL375_2.4; also elsewhere on the board
PA7-SPI1_MOSI: ADXL375_1.3, ADXL375_2.3; also elsewhere on the board
PA10-ID: R6.1; also elsewhere on the board
PA13-RED-P5: R15.1; also elsewhere on the board
PA14-GRN-P4: R16.1; also elsewhere on the board
PA15-YEL-P3: R17.1; also elsewhere on the board
PB2-BOOT1-MMA-INT: R8.1; also elsewhere on the board
PB3-SW: J2.6; also elsewhere on the board
PB4-BLU-P2: R18.1; also elsewhere on the board
PB5-MMA_AVDD: R13.1; also elsewhere on the board
PB6-SCL: J2.7, R19.2; also elsewhere on the board
PB7-SDA: J2.8, R20.2; also elsewhere on the board
PB10-SCL: R21.2; also elsewhere on the board
PB11-SDA: R22.2; also elsewhere on the board
PC0-ADXL1_INT1: ADXL375_1.7; also elsewhere on the board
PC1-ADXL1_INT2: ADXL375_1.8; also elsewhere on the board
PC2-ADXL2_INT1: ADXL375_2.7; also elsewhere on the board
PC3-ADXL2_INT2: ADXL375_2.8; also elsewhere on the board
PC4-REC_LED: J2.4; also elsewhere on the board
PC11-SDIO_D3: R1.1; also elsewhere on the board
R: LED_RED.1, R15.2
STAT: J2.5; also elsewhere on the board
VBUS: J2.3; also elsewhere on the board
Y: LED_YEL.1, R17.2

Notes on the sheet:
INDICATOR LEDS
I2C PULL-UPS
USB DFU REQUIRES STABLE LEVELS ON PA10, PB5, PB11, & PC11. PB2 MUST BE LOW DURING BOOT. PULL-UP RESISTORS PROVIDE STABLE LEVELS DURING BOOT.
ADXL375 RJ45 PORTS
IO PANEL RIBBON CABLE CONNECTOR

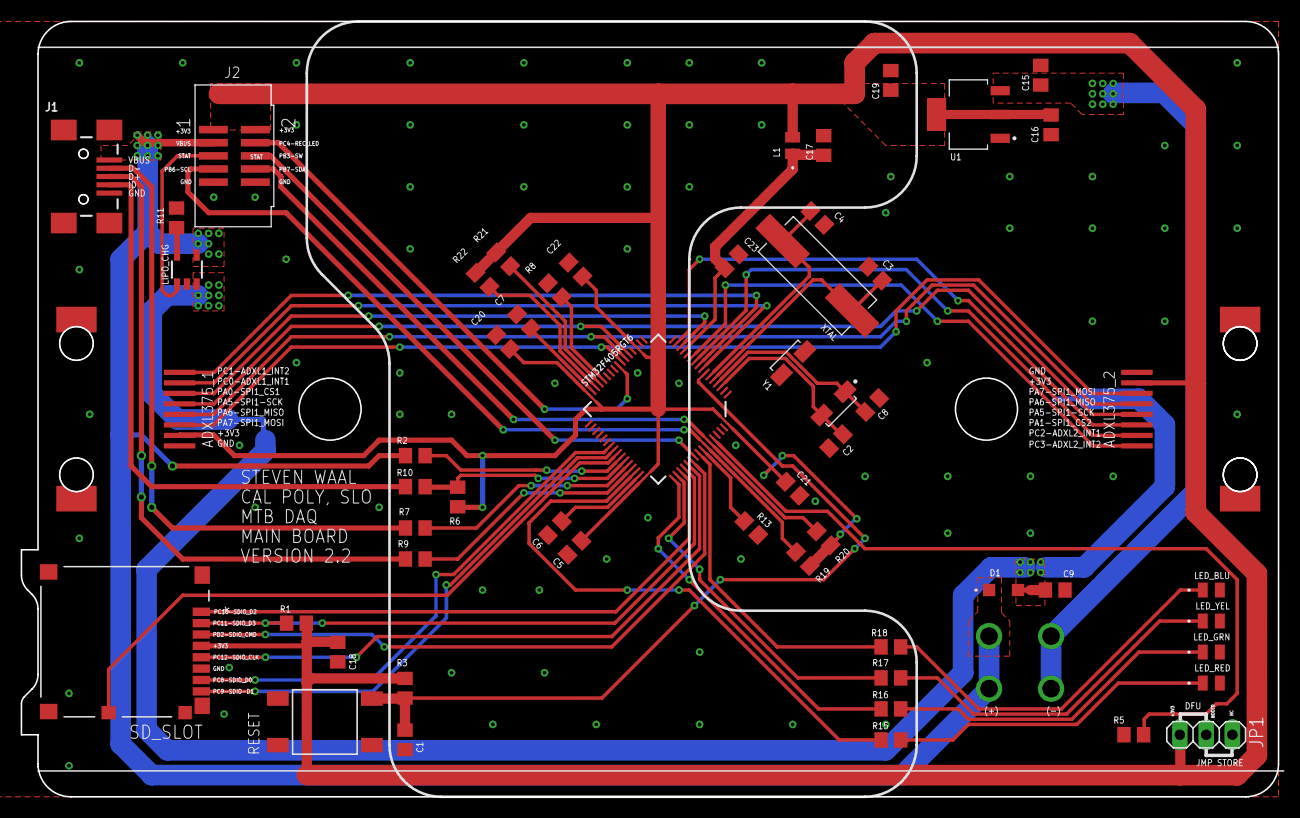
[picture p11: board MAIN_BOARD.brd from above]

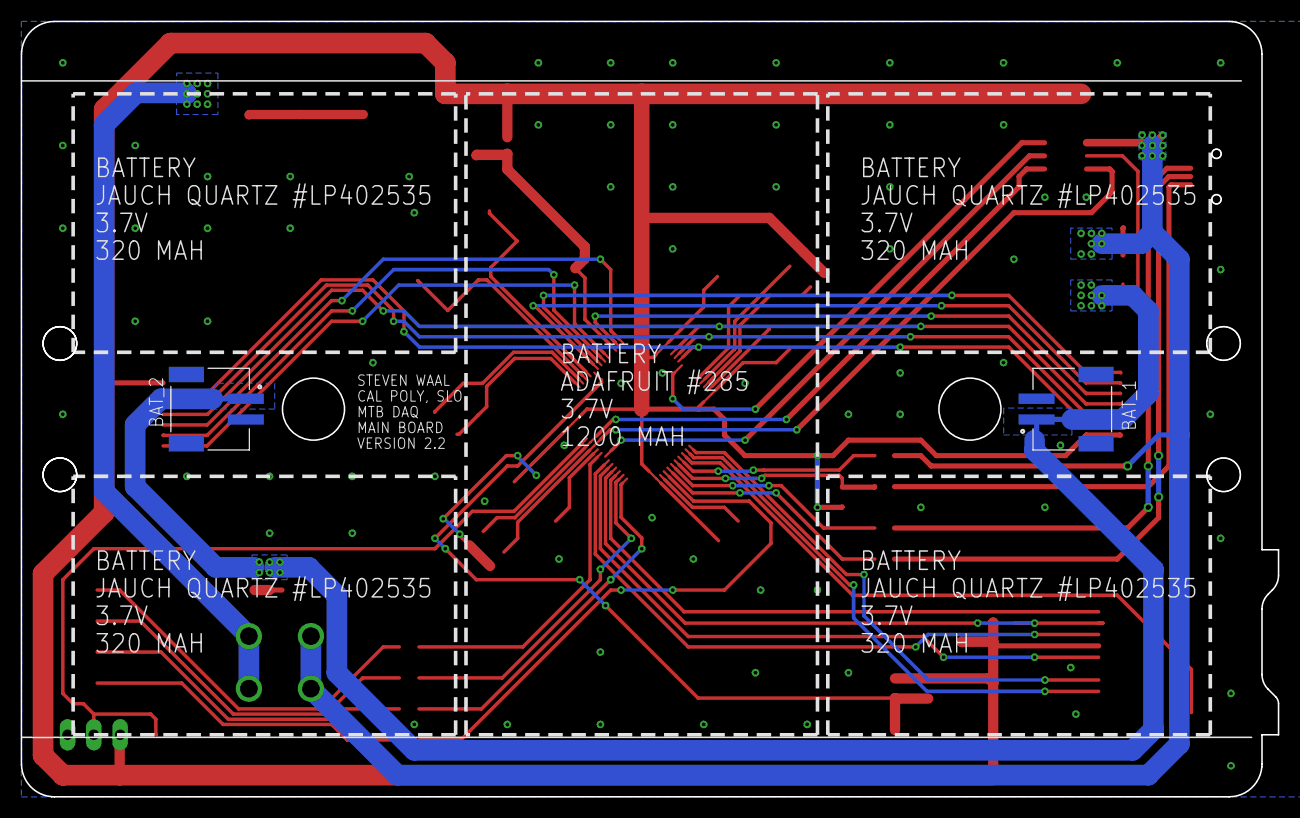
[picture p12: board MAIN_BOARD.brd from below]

Board: 2 copper layers, 121.6 x 75.0 mm, 59 parts (2 on the bottom side), 55 nets.

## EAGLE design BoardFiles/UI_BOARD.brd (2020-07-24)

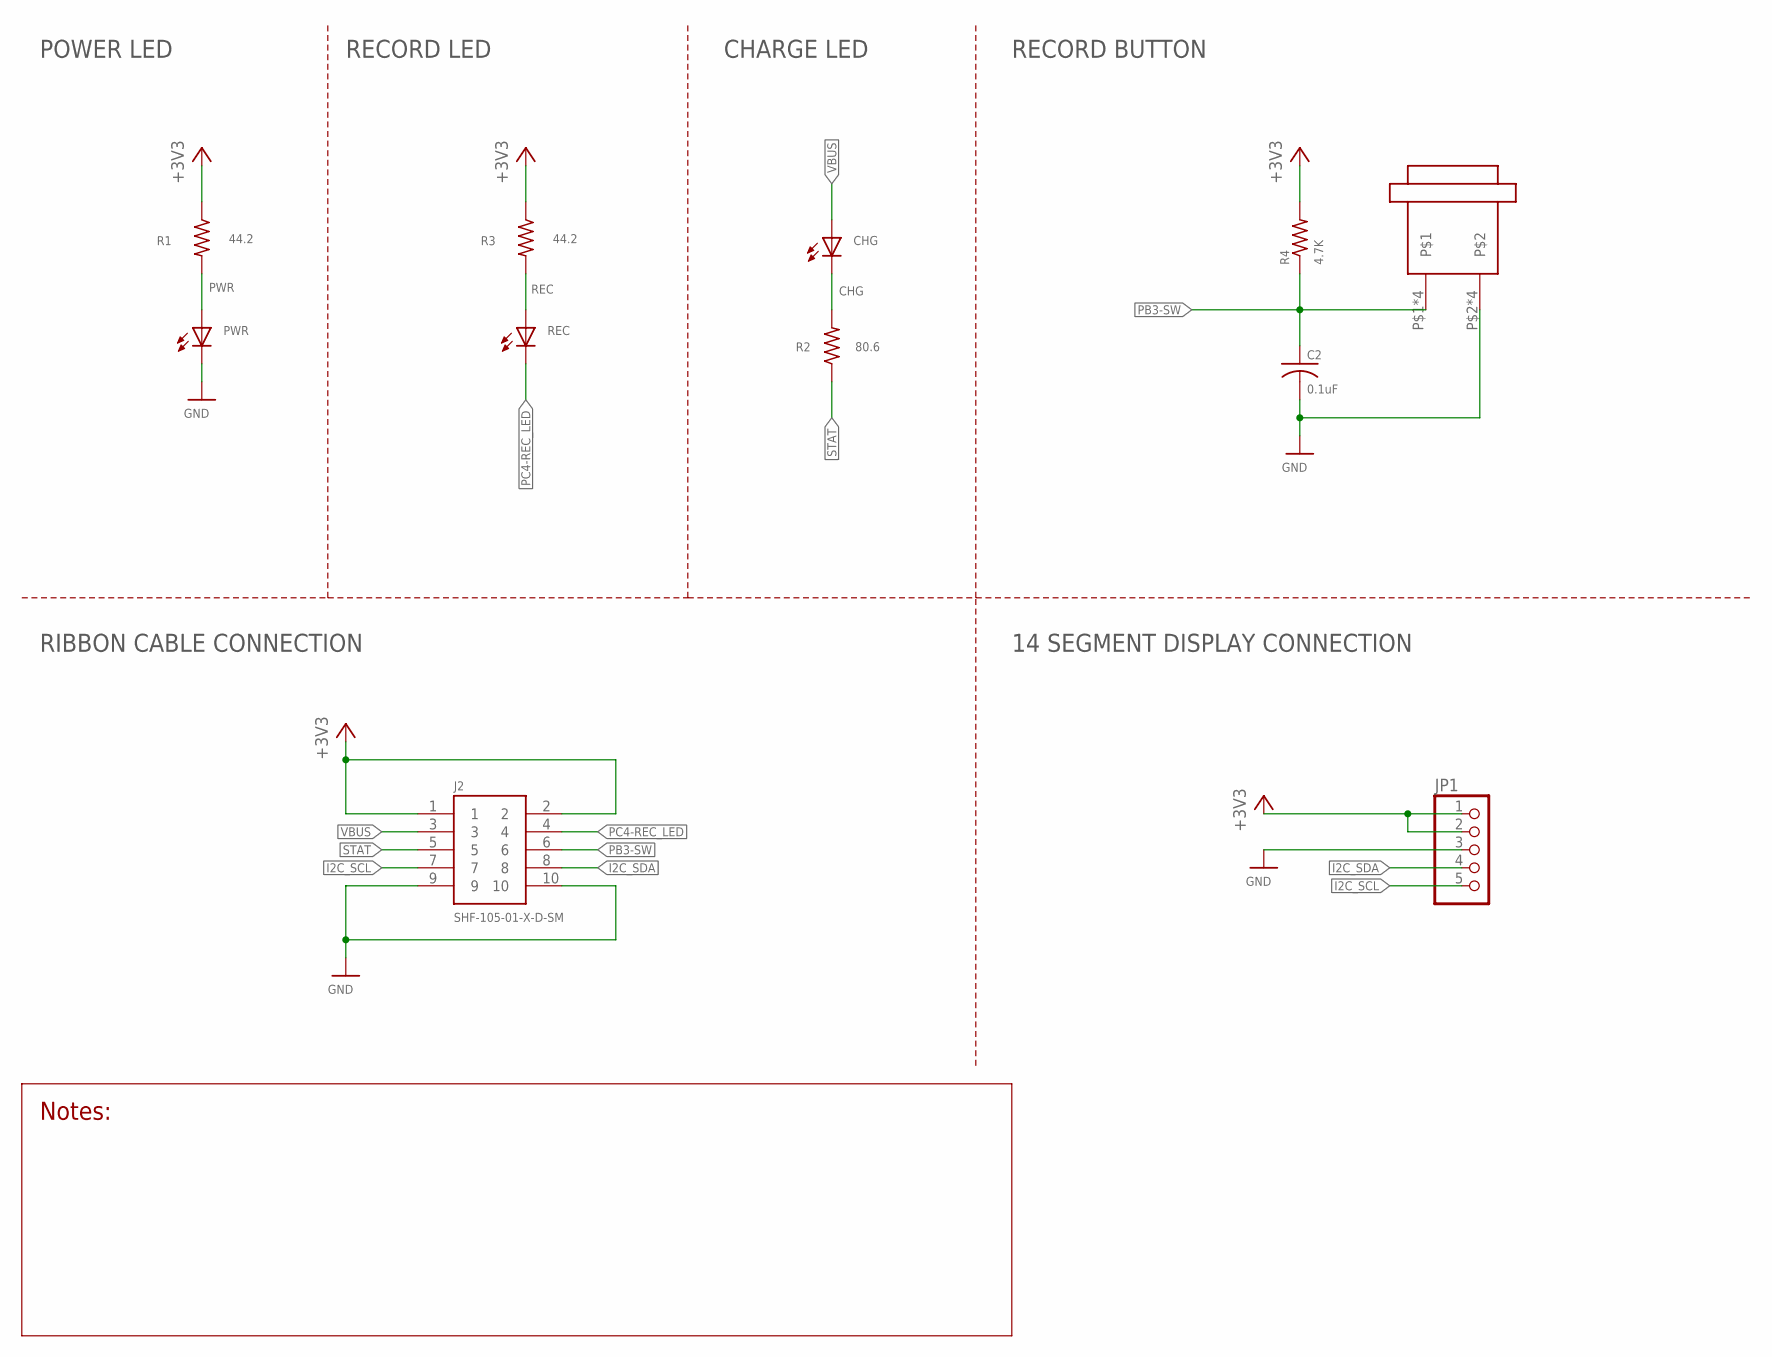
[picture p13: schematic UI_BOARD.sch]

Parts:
C2: 0.1uF; C0805
CHG: PANEL_MOUNT_LED
J2: SHF-105-01-X-D-SM
JP1: PINHD-1X5; 1X05
PWR: PANEL_MOUNT_LED
R1, R3: 44.2; R0805
R2: 80.6; R0805
R4: 4.7K; R0805
REC: PANEL_MOUNT_LED
U$4: PANEL_MOUNT_PUSH_BUTTON

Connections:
+3V3: J2.1, J2.2, JP1.1, JP1.2, R1.1, R3.1, R4.2
CHG: CHG.P$2 (2), R2.2
GND: C2.2, J2.9, J2.10, JP1.3, PWR.P$2 (2), U$4.P$2, U$4.P$4, U$4.P$6, U$4.P$8
I2C_SCL: J2.7, JP1.5
I2C_SDA: J2.8, JP1.4
PB3-SW: C2.1, J2.6, R4.1, U$4.P$1, U$4.P$3, U$4.P$5, U$4.P$7
PC4-REC_LED: J2.4, REC.P$2 (2)
PWR: PWR.P$1 (1), R1.2
REC: R3.2, REC.P$1 (1)
STAT: J2.5, R2.1
VBUS: CHG.P$1 (1), J2.3

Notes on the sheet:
POWER LED
RECORD LED
CHARGE LED
RECORD BUTTON
14 SEGMENT DISPLAY CONNECTION
RIBBON CABLE CONNECTION

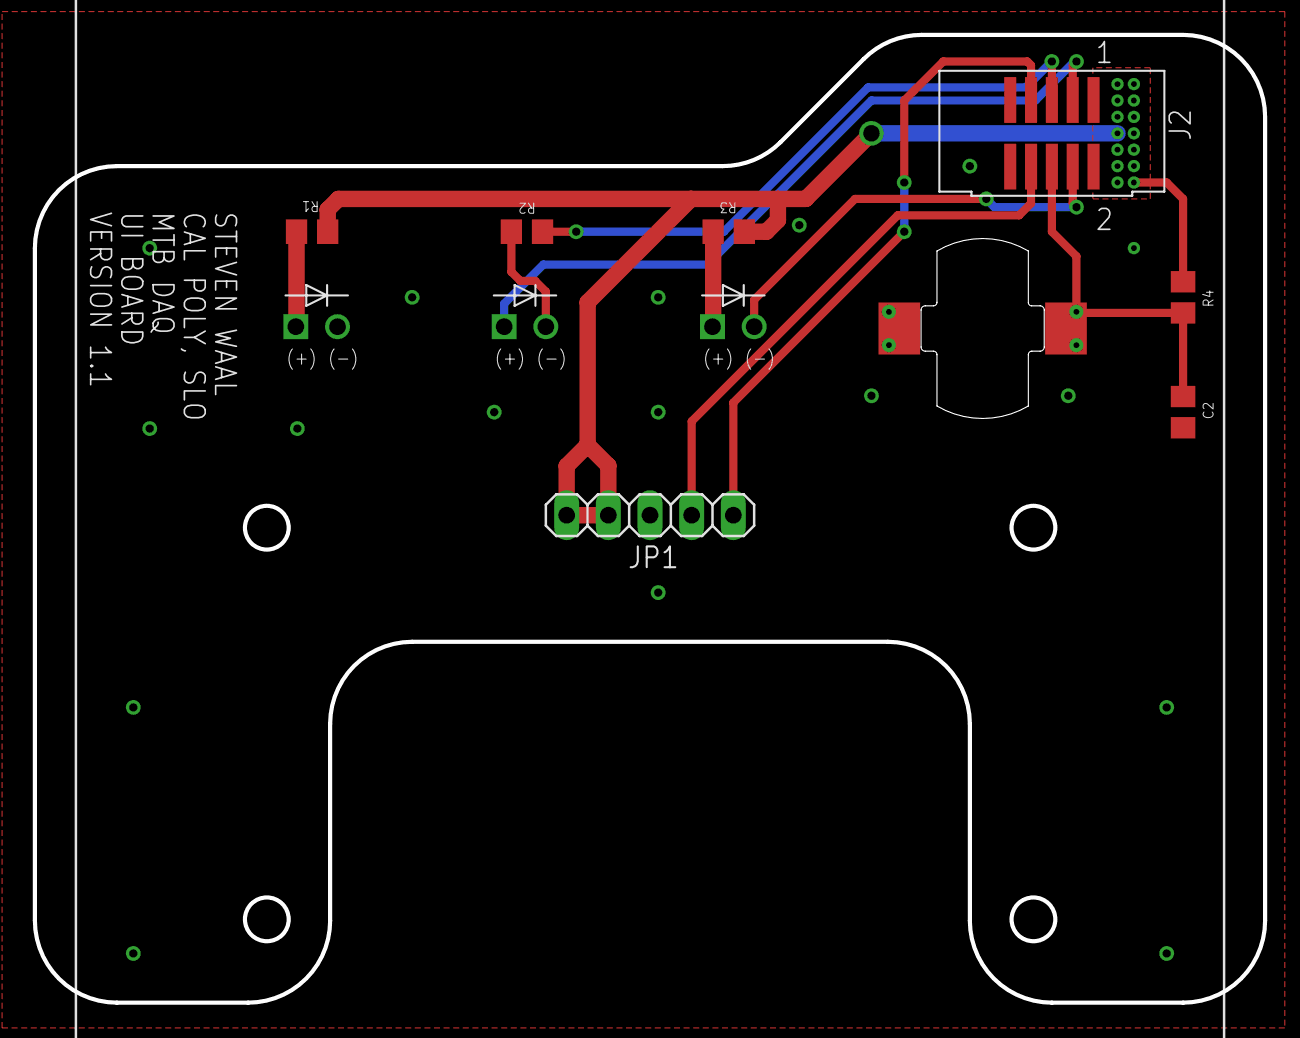
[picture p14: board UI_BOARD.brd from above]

Board: 2 copper layers, 75.0 x 59.0 mm, 11 parts (0 on the bottom side), 11 nets.

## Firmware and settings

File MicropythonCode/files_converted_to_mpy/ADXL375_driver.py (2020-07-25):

# ADXL375 DRIVER 
#=========================================================================
# @file ADXL375_driver.py
#=========================================================================
# ABOUT:
# This code implements a driver for the ADXL375BCCZ-ND accelerometer. More
# information about the accelerometer and links to the datasheets can be 
# found here: https://www.digikey.com/product-detail/en/analog-devices-inc/ADXL375BCCZ/ADXL375BCCZ-ND/4376342
#=========================================================================
# WRITTEN BY: Steven Waal
# DATE: 05.28.2019
#=========================================================================
# NOTES:
# 05.28.2019 - File created (SRW)
# 06.07.2019 - Added more constants and fixed read/write methods
# 09.07.2019 - Added more bit masks/constants. Added more functions.
# 03.05.2020 - Added functions to configure interrupts and FIFO buffer.
# 06.11.2020 - Final comments added, code cleaned up
#=========================================================================
# SCHEMATIC:
# The axes of the ADXL375 are configured as follows(note the mark in the 
# upper right hand corner)                                                                        
#                                                                         
#                                                                         
#      Z AXIS                                                                     
#        |                                                     
#        |           Y AXIS                                                         
#        |          /     ___________________________________                                                     
#        |         /     /                                  /|                                      
#        |        /     /                              *   / |                                      
#        |       /     /                                  / /                                       
#        |      /     /                                  / /                                     
#        |     /     /                                  / /                                         
#        |    /     /                                  / /                                          
#        |   /     /                                  / /                                           
#        |  /     /__________________________________/ /                                                             
#        | /      |__________________________________|/                                                              
#        |/                                                                     
#        |_________________________________________________________ X AXIS                                                                     
#
#
#
#=========================================================================
# COPYRIGHT:
# @copyright This program is copyrighted by Steven Waal and released under 
# the GNU Public License, version 3.0.
#=========================================================================










#=========================================================================
# IMPORT MODULES
#=========================================================================
import micropython
#from pyb import SPI










#=========================================================================
# CLASS DEFINITION
#=========================================================================
class ADXL375:
    ''' This class defines a driver for the Analog Devices ADXL375BCCZ-ND accelerometer.'''

    #=========================================================================
    # CONSTANTS
    #=========================================================================
    # -------------------------------------
    # GENERAL
    # -------------------------------------
    SCALE_FACTOR        = 0.0488            # [g/LSB]

    # -------------------------------------
    # BIT MASKS
    # -------------------------------------
    # These masks are used to set reading and writing protocols.
    READ_MASK           = const(0b10000000)
    WRITE_MASK          = const(0b00000000)
    READ_2_BYTES_MASK   = const(0b01000000)

    # -------------------------------------
    # REGISTER MAP (page 20 of datasheet)
    # -------------------------------------
    # All registers in the ADXL375 are eight bits in length.
    DEVID               = 0x00              # Device ID
    # Reserved            0x01 to 0x1C      # Reserved; do not access
    THRESH_SHOCK        = 0x1D              # Shock threshold
    OFSX                = 0x1E              # X-axis offset
    OFSY                = 0x1F              # Y-axis offset
    OFSZ                = 0x20              # Z-axis offset
    DUR                 = 0x21              # Shock duration
    Latent              = 0x22              # Shock latency
    Window              = 0x23              # Shock window
    THRESH_ACT          = 0x24              # Activity threshold
    THRESH_INACT        = 0x25              # Inactivity threshold
    TIME_INACT          = 0x26              # Inactivity time
    ACT_INACT_CTL       = 0x27              # Axis enable control for activity and inactivity detection
    SHOCK_AXES          = 0x2A              # Axis control for single shock/double shock
    ACT_SHOCK_STATUS    = 0x2B              # Source of single shock/double shock
    BW_RATE             = 0x2C              # Data rate and power mode control
    POWER_CTL           = 0x2D              # Power saving features control
    INT_ENABLE          = 0x2E              # Interrupt enable control
    INT_MAP             = 0x2F              # Interrupt mapping control
    INT_SOURCE          = 0x30              # Interrupt source
    DATA_FORMAT         = 0x31              # Data format control
    DATAX0              = 0x32              # X-axis Data 0
    DATAX1              = 0x33              # X-axis Data 1
    DATAY0              = 0x34              # Y-axis Data 0
    DATAY1              = 0x35              # Y-axis Data 1
    DATAZ0              = 0x36              # Z-axis Data 0
    DATAZ1              = 0x37              # Z-axis Data 1
    FIFO_CTL            = 0x38              # FIFO control
    FIFO_STATUS         = 0x39              # FIFO status

    # -------------------------------------
    # REGISTER BIT DESCRIPTIONS
    # -------------------------------------
    # These constants define either bit masks for individual bits in each
    # register, or constant values that can be used to set various settings
    # in the register.
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

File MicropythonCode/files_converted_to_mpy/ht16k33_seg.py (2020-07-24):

# ht16k33 Segment 
#=========================================================================
# @file ht16k33_seg.py
#=========================================================================
# ABOUT:
# This code implements a driver for the Adafruit 4 character 4 segment
# display controlled by the ht16k33 LED driver.
#=========================================================================
# WRITTEN BY: Dale Weber
# SOURCE: https://github.com/hybotics/micropython-adafruit-ht16k33
#=========================================================================

from ht16k33_matrix import HT16K33


CHARS = (
    0b00000000, 0b00000000, #
    0b01000000, 0b00000110, # !
    0b00000010, 0b00100000, # "
    0b00010010, 0b11001110, # #
    0b00010010, 0b11101101, # $
    0b00001100, 0b00100100, # %
    0b00100011, 0b01011101, # &
    0b00000100, 0b00000000, # '
    0b00100100, 0b00000000, # (
    0b00001001, 0b00000000, # )
    0b00111111, 0b11000000, # *
    0b00010010, 0b11000000, # +
    0b00001000, 0b00000000, # ,
    0b00000000, 0b11000000, # -
    0b00000000, 0b00000000, # .
    0b00001100, 0b00000000, # /
    0b00001100, 0b00111111, # 0
    0b00000000, 0b00000110, # 1
    0b00000000, 0b11011011, # 2
    0b00000000, 0b10001111, # 3
    0b00000000, 0b11100110, # 4
    0b00100000, 0b01101001, # 5
    0b00000000, 0b11111101, # 6
    0b00000000, 0b00000111, # 7
    0b00000000, 0b11111111, # 8
    0b00000000, 0b11101111, # 9
    0b00010010, 0b00000000, # :
    0b00001010, 0b00000000, # ;
    0b00100100, 0b01000000, # <
    0b00000000, 0b11001000, # =
    0b00001001, 0b10000000, # >
    0b01100000, 0b10100011, # ?
    0b00000010, 0b10111011, # @
    0b00000000, 0b11110111, # A
    0b00010010, 0b10001111, # B
    0b00000000, 0b00111001, # C
    0b00010010, 0b00001111, # D
    0b00000000, 0b11111001, # E
    0b00000000, 0b01110001, # F
    0b00000000, 0b10111101, # G
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
)
NUMBERS = (
    0x3F, # 0
    0x06, # 1
    0x5B, # 2
    0x4F, # 3
    0x66, # 4
    0x6D, # 5
    0x7D, # 6
    0x07, # 7
    0x7F, # 8
    0x6F, # 9
    0x77, # a
    0x7C, # b
    0x39, # C
    0x5E, # d
    0x79, # E
    0x71, # F
    0x40, # -
)


class Seg14x4(HT16K33):
    #	If True, debugging code will be executed
    debug = False

    def scroll(self, count=1):
        if count >= 0:
            offset = 0
        else:
            offset = 2
        for i in range(6):
            self.buffer[i + offset] = self.buffer[i + 2 * count]

    def put(self, char, index=0):
        if not 0 <= index <= 3:
            return
        if not 32 <= ord(char) <= 127:
            return
        if char == '.':
            self.buffer[index * 2 + 1] |= 0b01000000
            return
        c = ord(char) * 2 - 64
        self.buffer[index * 2] = CHARS[1 + c]
        self.buffer[index * 2 + 1] = CHARS[c]

    def push(self, char):
        if char != '.' or self.buffer[7] & 0b01000000:
            self.scroll()
            self.put(' ', 3)
        self.put(char, 3)

    def text(self, text):
        for c in text:
            self.push(c)

    '''
		Display a floating point or integer number on the Adafruit HT16K33 based displays
		
		Param: number - The floating point or integer number to be displayed, which must be
			in the range 0 (zero) to 9999 for integers and floating point or integer numbers
			and between 0.0 and 999.0 or 99.00 or 9.000 for floating point numbers.
		Param: decimal - The number of decimal places for a floating point number if decimal
			is greater than zero, or the input number is an integer if decimal is zero.

        Returns: The output text string to be displayed.
    '''
    def number(self, number, decimal = 0):
        s = "{:f}".format(number)
        places = 1

        if self.debug:
            print("(1) number = {0}, places = {1}, decimal = {2}, s = '{3}'".format(number, places, decimal, s))

        if (len(s) > 5):
            dot = s.find('.')

            if (dot > 5):
                raise ValueError("Input overflow - {0} is too large for the display!".format(number))
            elif ((dot > 0) and (decimal == 0)):
                places = dot

        if ((places <= 0) and (decimal > 0)):
            self.fill(False)
            places = 4
			
            if '.' in s:
                places += 1

        if self.debug:
            print("(2) places = {0}, dot = '{1}', decimal = {2}, s = '{3}'".format(places, dot, decimal, s))

        #	Set decimal places, if number of decimal places is specified (decimal > 0)	
        if ((places > 0) and (decimal > 0) and (dot > 0) and (len(s[places:]) > decimal)):
            txt = s[:dot + decimal + 1]
        elif (places > 0):
            txt = s[:places]

        if self.debug:
            print("(3) places = {0}, s = '{1}', decimal = {2}, txt = '{3}'".format(places, s, decimal, txt))
            print()

        if (len(txt) > 5):
            raise ValueError("Output string ('{0}') is too long!".format(txt))

        self.text(txt)
        
        return txt

    def hex(self, number):
        s = "{:x}".format(number)
        if len(s) > 4:
            raise ValueError("Overflow")
        self.fill(False)
        self.text(s)


class Seg7x4(Seg14x4):
    P = [0, 2, 6, 8] #  The positions of characters.

    def scroll(self, count=1):
        if count >= 0:
            offset = 0
        else:
            offset = 1
        for i in range(3):
            self.buffer[self.P[i + offset]] = self.buffer[self.P[i + count]]

    def push(self, char):
        if char in ':;':
            self.put(char)
        else:
            super().push(char)

    def put(self, char, index=0):
        if not 0 <= index <= 3:
            return
        char = char.lower()
        if char == '.':
            self.buffer[self.P[index]] |= 0b10000000
            return
        elif char in 'abcdef':
            c = ord(char) - 97 + 10
        elif char == '-':
            c = 16
        elif char in '0123456789':
            c = ord(char) - 48
        elif char == ' ':
            c = 0x00
        elif char == ':':
            self.buffer[4] = 0x02
            return
        elif char == ';':
            self.buffer[4] = 0x00
            return
        else:
            return
        self.buffer[self.P[index]] = NUMBERS[c]

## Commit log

2020-07-25 Slight correction to scaling factor
    [ADXL375_driver.py]
2020-07-25 Updated BOM
    [BOM.xlsx]

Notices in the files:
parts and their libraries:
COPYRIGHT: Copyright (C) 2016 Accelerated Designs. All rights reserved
